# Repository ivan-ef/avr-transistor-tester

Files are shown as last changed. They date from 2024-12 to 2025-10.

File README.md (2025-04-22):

# AVR Transistor Tester

Component/Transistor tester based on famous [AVR Transistor Tester](https://www.mikrocontroller.net/articles/AVR_Transistortester) project. The reason I decided to create a custom PCB is that currently there is not good kit or complete device available that would fit my wishes:

- ATMega644 MCU
- 2.4" 65K colors LCD
- Rotary encoder
- USB-C charger with Li-Po battery
- Higher grade/precision components

Most of Chinese versions are starting to use fake or non-original Microchip MCUs that prevents their software upgrades and economy on components makes them less accurate. I didn't include a lot of hardware options, because I primarily using the device for measuring passive components and transistors used in guitar pedals building.

## Complete unit

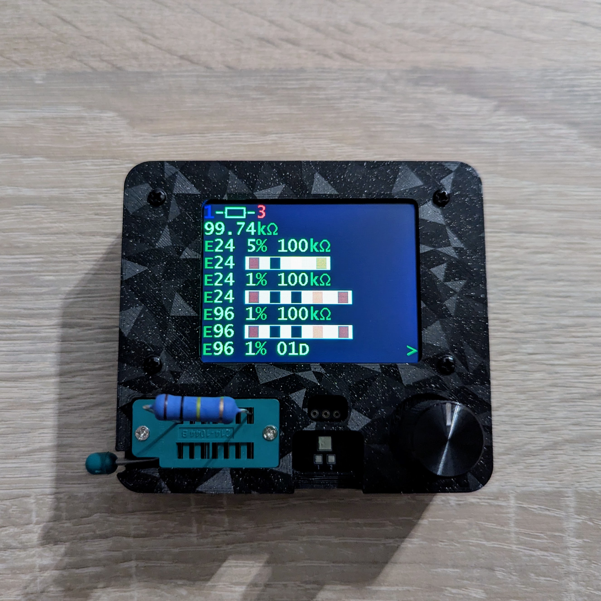
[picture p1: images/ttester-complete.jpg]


## PCB

I used SMD assembly service at JLCPCB and ended up with a set 5 PCBs cost around 25$ each. But since SMD components used there is not the smallest size ones, it is 100% possible to solder everything by hand.

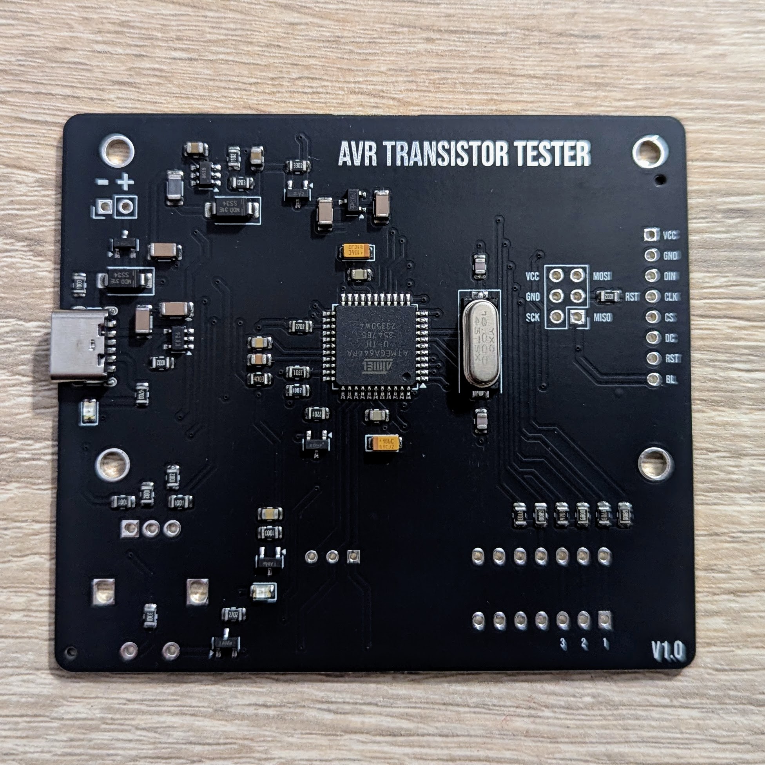
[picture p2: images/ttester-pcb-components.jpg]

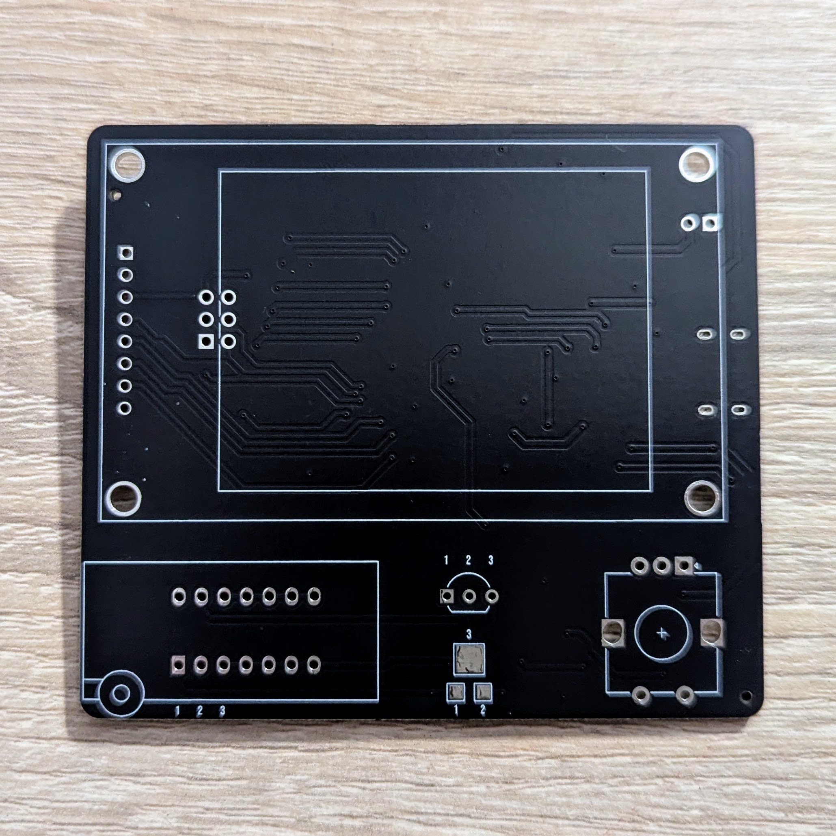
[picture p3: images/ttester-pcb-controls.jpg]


## Schematic

[PDF](https://github.com/vitaliy-bobrov/avr-transistor-tester/blob/main/schematic.pdf)

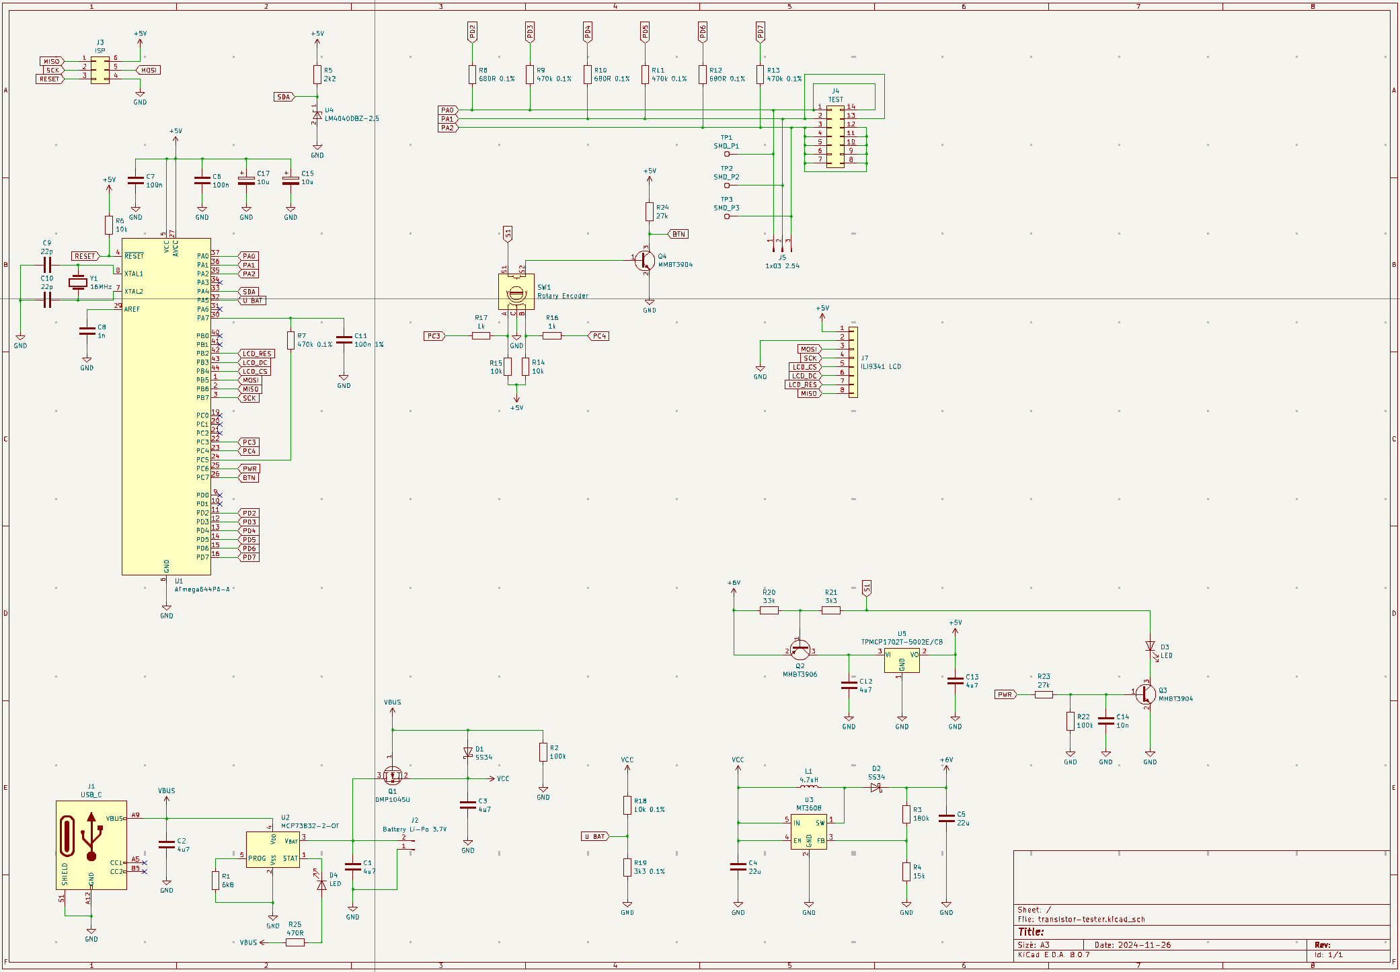
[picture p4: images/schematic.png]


## Hardware

PCB has almost everything as SMD assembly and requires a few components to be soldered by hand:

- Rotary Encoder - basically any common one would work here, but I've used BOURNS PEC11R-4220K-S0024. It is available at most big components suppliers. My personal choice was [TME](https://www.tme.eu/pl/details/pec11r-4220k-s0024/enkodery-inkrementalne/bourns/).
- ZIF 14 pin socket - again you could use any common one. I used CONNFLY DS1044-140G from [TME](https://www.tme.eu/pl/details/ds1044-140g/podstawki-testowe/connfly/)
- 2.4" 65K colors LCB. Not sure if other ILI9341 controller based would have the same pins/size. I used [Waveshare 18366](https://www.waveshare.com/2.4inch-lcd-module.htm) which is not expensive and commonly available. At [TME](https://www.tme.eu/pl/details/wsh-18366/wyswietlacze-lcd-graficzne/waveshare/18366/) too ;)
- 2.54mm spaced 2x3 pins for ISP - this could be left without pins soldered, then just ensure you have good contact between the PCB and programming pins.
- 2.54mm 3 pin socket for components/transistors - just alternative for ZIF socket
- Any Li-Po or Li-Ion battery with work with the charger IC, but the PCB was designed with Li-Po in mind due to size. I used [550mA battery](https://www.tme.eu/pl/details/aky-lp503040/akumulatory/akyga-battery/aky0185/), but you could use any other that would fit about 55x50mm size.

## Software

The software used in m-software version 1.55m (see [docs](https://github.com/madires/Transistortester-Warehouse/tree/master/Documentation)), but k-software could be used as well. The pins assignment is based on project docs suggested one. Precompiled version is in the [software](https://github.com/vitaliy-bobrov/avr-transistor-tester/blob/main/software/) folder.

### Software compilation

1. Install AVR tools for your operating system and programmer you are using (ex. avrdude)
2. Navigate to software folder
3. Run `make`
4. Connect programmer to the ISP pins on the PCB
5. Run `make fuses` to set MCU fuses
6. Run `make upload` to upload firmware

## Enclosure

I designed a simple 3D printable enclosure that fits the PCB and provides easy access to ISP pins and USB-C charger. STEP files are located in the [3d-enclosure](https://github.com/vitaliy-bobrov/avr-transistor-tester/blob/main/3d-enclosure/) folder. Printing profile is available at [MakerWorld](https://makerworld.com/en/models/883799#profileId-838469) which would be handy if you have a BambuLab 3D printer.

The assembled PCB with display is mounted to enclosure using spacers that came with Waveshare display using 4 x M2x8mm and 4 x M2x16mm screws. the battery is fixed on the backplate with double sided 3M foam.

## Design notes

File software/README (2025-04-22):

------------------------------------------------------------------------------

            ReadMe for the Component Tester firmware (m-firmware)

        (c) 2012-2025 by Markus Reschke (madires@theca-tabellaria.de)

------------------------------------------------------------------------------

Last edit:   2025-03-27
For version: 1.55m

Content
  - About
  - Safety Advice
  - License
    - Additional Disclaimer
  - What's different?
  - Source Code
  - Supported Hardware
  - Building the Firmware
  - Busses & Interfaces
    - I2C/SPI
    - TTL Serial
    - OneWire
  - Displays
    - Fonts and Symbols
    - HD44780
    - ILI9163
    - ILI9341/ILI9342
    - ILI9481
    - ILI9486
    - ILI9488
    - PCD8544
    - PCF8814
    - SH1106
    - SSD1306
    - ST7036
    - ST7565R
    - ST7735
    - ST7920
    - STE2007/HX1230
    - VT100 Terminal
  - Test push button and other input options
    - Test Key
    - Rotary Encoder
    - Increase/Decrease Buttons
    - Touch Screen
  - User Interface
    - Buzzer
  - Communication with PC
    - Serial Output
    - Automation
    - VT100 Output
  - Power-On
  - Probing
  - Battery Monitoring
  - Power Off
  - Menu
    - PWM Tool
    - Square Wave Generator
    - Zener Tool
    - Logic Probe
    - Continuity Check
    - ESR Tool
    - Capacitor Leakage Check
    - R/C/L Monitors
    - LC Meter
    - Frequency Counter
      - Basic Counter
      - Extended Counter
    - Ring Tester
    - Event Counter
      - Trigger Output
    - Rotary Encoder
    - Contrast
    - IR RC Detector/Decoder
    - IR RC Transmitter
    - Opto Coupler Tool
    - Photodiode Check
    - Diode/LED Quick-Check
    - Servo Check
    - OneWire Scan
    - DS18B20/DS18S20 Temperature Sensors
    - DHTxx Temperature & Humidity Sensors
    - MAX6675/MAX31855 Thermocouple Converters
    - BH1750 Ambient Light Sensor
    - INA226 Power Monitor
    - Flashlight
    - Voltmeter 0-5 V DC
    - Self Test
    - Self Adjustment
    - Save/Load
    - Show Values
    - Font/Symbols
    - Power Off
    - Exit
    - Order of Menu Items
  - Resistors
  - Capacitors
  - Inductors
  - Discharging Components
  - ADC Oversampling
  - Displaying Results
    - Additional Hints
      - BJTs
      - FETs
      - TRIACs
      - CLDs
      - SUS/SBSs
  - Unsupported Components
  - Workarounds for some Testers
  - Known Issues
  - Support
  - Change Log
  - Remote Commands
  - Helpful Links
  - References

* About

The Component Tester is based on the project of Markus Frejek [1&2] and the
successor of Karl-Heinz Kübbeler [3&4]. It's an alternative firmware for
Karl-Heinz' current Transistortester circuit and comes with several changes in
the user interface and the methods used for probing and measuring. It also
offers a few additional features. While Karl-Heinz provides an official
release supporting also older ATmega MCUs, this firmware does require an
ATmega with 32 kB flash at least.

Hints:
- Run the self-adjustment for a new tester or if you've done any
  modifications, like a firmware update or changing probe leads.
- The Component Tester isn't an LCR meter. It can measure capacitance and
  inductance within some limits.

* Safety Advice

The Component Tester is no DMM! It's a simple tester for components capable
of measuring several things. The probes aren't protected in any way and
won't survive higher voltages than 5 V. Don't use the tester for live circuits!
Just use it for unsoldered electronic components! If you test a capacitor make
sure it's discharged before connecting the probes. This isn't just the Safety
Sally, your life may be at risk if you connect the probes to a live circuit
or a power supply (or even mains). 

* License

The original author hasn't provided any information about the licence under
which the firmware is distributed. He only stated that it's open source and
any commercial user should contact him. Unfortunately we (Karl-Heinz and I)
haven't found any way to contact him. To remedy this problem I've chosen an
open source license at 2016-01-01, after giving the original author more than
sufficient time to tell us his wishes regarding the license. Since the source
code of this firmware version is a major rewrite with tons of new code and
features, I think that this approach is justified.

Licensed under the EUPL v. 1.2

+ Additional Disclaimer

Product or company names are possibly trademarks of the respective owners.

* What's different?

Karl-Heinz has done a really great documentation of the tester. I recommend
to read it. Therefore I'll tell you just about the major differences to the
k-firmware:

- user interface
  + No worries! ;)
  + touch screen
  + remote commands
  + two sets of adjustment values
- adaptive component discharge function
- resistance measurement
  + dedicated method for resistances <10 Ohms (instead of using ESR check)
- capacitance measurement
  + starts at 5 pF
  + additional method for caps from 4.7 µF up to 47 µF
  + correction/compensation method
- no SamplingADC() for very low capacitance or inductance
- diodes
  + detection logic
- BJTs
  + V_f is interpolated for a more suitable (virtual) I_b based on hFE
  + detection of Germanium BJTs with high leakage current
  + detection of Schottky-clamped BJTs
- JFETs
  + detection of JFETs with very low I_DSS
- TRIACs
  + detection of MT1 and MT2
- IR RC detector and decoder
- IR RC transmitter
- opto coupler check
- RC servo check
- OneWire (plus sensors DS18B20 and DS18S20)
- DHTxx Sensors
- event counter
- ring tester (LOPT/FBT tester)
- logic probe
- continuity check
- MAX6675/MAX31855 thermocouple converters
- BH1750 Ambient Light Sensor
- INA226 Power Monitor
- flashlight / general purpose switched output
- structured source code
- simple frameworks for displays and data busses
- some more I couldn't think of right now

There are more details in the sections below.

* Source Code

The first m-firmware was based on Karl-Heinz' source code. A lot of cleaning
up was done, like more remarks, renamed variables, re-structured functions,
large functions splitted up into several smaller ones and what have you. After
that the m-firmware moved on to become an independent version. For example,
simple frameworks for displays and interface busses were added. I hope the
code is easy to read and maintain.

You can download the lastest firmware from following sites:
- https://github.com/madires/Transistortester-Warehouse
- https://github.com/kubi48/TransistorTester-source/tree/master/Markus
  (https://github.com/Mikrocontroller-net/transistortester/tree/master/Software/Markus)

* Supported Hardware

The firmware runs on all testers which are compatible with the standard
circuit shown in Karl-Heinz' documentation and which use one of the
following MCUs:
  - ATmega 328
  - ATmega 324/644/1284
  - ATmega 640/1280/2560

You can customize pin assigments if required. The display may be a character
or graphic type (monochrome or color). Please see section 'Displays' for
supported controllers.

Following hardware options are supported:

  user interface
  - rotary encoder
  - additional push buttons (in/decrease)
  - touch screen
  - serial interface (TTL, RS232, USB-serial adpater) 
  - buzzer

  enhancements
  - external 2.5 V voltage reference
  - fixed adjustment cap
  - protection relay for discharging caps

  additional checks and measurements
  - Zener check / measurement of external voltage < 50 V
  - basic frequency counter
  - extended frequency counter
    with prescaler and crystal oscillators for low and high frequencies
  - fixed IR RC receiver
  - LC meter
  - ring tester (LOPT/FBT tester)
  - logic probe
  - fixed DS18B20/DS18S20 temperature sensors
  - MAX6675/MAX31855 thermocouple converters
  - BH1750 ambient light sensor
  - INA226 power monitor
  - flashlight / general purpose switched output

* Building the Firmware

First edit the Makefile to specify your MCU model, frequency, oscilator
type and programmer settings. All other settings are moved to a global
config.h and a MCU specific config-<MCU>.h. The file 'Clones' lists
settings for various tester versions/clones. If you have a tester not listed,
please email the settings to the author to help other users.

In config.h please choose hardware and software options, the language for the
UI, and change any default values if required. All settings and values are
explained in the file, so I won't discuss them here in depth. 

Hardware options:
- additional keys
  - rotary encoder
  - increase/decrease push buttons
  - touch screen
- 2.5 V voltage reference
- relay based cap discharger
- Zener voltage measurement
- frequency counter (basic and extendend version)
- event counter
- LC Meter
- ring tester (LOPT/FBT tester)
- IR detector/decoder for remote controls
  (fixed IR receiver module)
- fixed cap for self-adjustment of voltage offsets
- SPI bus (bit-bang and hardware)
- I2C bus (bit-bang and hardware)
- TTL Serial (bit-bang and hardware)
- OneWire bus (bit-bang)
- ...

The external 2.5 V voltage reference should be only enabled if it's at least
10 times more precise than the voltage regulator. Otherwise it would make
the results worse. If you're using an MCP1702 with a typical tolerance of
0.4 % as voltage regulator you really don't need a 2.5 V voltage reference.

And of course the software options:
- PWM generator (2 variants)
- inductance measurement
- ESR measurement and in-circuit ESR measurement
- check for rotary encoders
- squarewave signal generator (requires additional keys)
- IR detector/decoder for remote controls
  (IR receiver module connected to probes)
- IR RC transmitter (IR LED with driver transistor)
- check for opto couplers
- servo check (requires additional keys, display with >2 lines)
- detection of UJTs
- capacitor leakage check
- DS18B20/DS18S20 temperature sensors
- color coding for probes (requires color graphics display)
- output of components found also via TTL serial, e.g. to a PC
- remote commands for automation via TTL serial
- output of reverse hFE for BJTs
- DHT11/22 temperature and humidity sensor
- ...

Please choose the options carefully to match your needs and the MCU's
ressources, i.e. RAM, EEPROM and flash memory. If the firmware exceeds the
MCU's flash size, try to disable some options you don't need.

Available UI languages:
- Brazilian Portuguese
  - provided by wandows@EEVblog
- Czech
  - provided by Kapa
  - font based on ISO 8859-1
- Czech 2
  - provided by Bohu
  - font with Czech characters based on ISO 8859-2
- Danish
  - provided by glenndk@mikrocontroller.net
  - needs minor changes in the font
- English (default)
- French
  - provided by moimem@EEVblog
- German
- Italian
  - provided by Gino_09@EEVblog
- Polish
  - provided by Szpila
- Romanian
  - provided by Dumidan@EEVblog
- Russian
  - provided by indman@EEVblog
  - font with cyrillic characters based on Windows-1251
- Russian 2
  - provided by hapless@@EEVblog
  - font with cyrillic characters based on Windows-1251
  - alternative text 
- Spanish
  - provided by pepe10000@EEVblog

For number values a decimal fraction is indicated by a dot, but you can change
that to a comma if you like by enabling the corresponding setting.

For MCU specific settings, like pin assignments and display, edit 
config_<MCU>.h:
- ATmega 328                config_328.h
- ATmega 324/644/1284       config_644.h
- ATmega 640/1280/2560      config_1280.h

The display has to provide 2 lines with 16 characters each, at least. For
graphic displays select a font which is small enough to match the
requirements.

After editing the Makefile, config.h and config-<MCU>.h please run 'make' or
whatever toolchain you have to compile the firmware. This will create two
files:
- ComponentTester.hex   firmware in Intel hex format
- ComponentTester.eep   EEPROM data in Intel hex format

The firmware will be written to the Flash and the EEPROM data to the EEPROM.
The data contains two sets of default adjustment values, texts and tables.
When you update the firmware and like to keep the old adjustment values in the
EEPROM you can enable DATA_FLASH in config.h to move texts and tables into the
firmware. In that case only the firmwmare needs be programed, the EEPROM stays
untouched.

The Makefile provides following additional targets:
- clean     to delete all object and firmware files
- fuses     to set the ATmega's fuse bits (via avrdude)
- upload    to program the firmware and EEPROM data (via avrdude)
- prog_fw   to program only the firmware (via avrdude)
- prog_ee   to program only the EEPROM data (via avrdude)

Hints on compiler/linker optimizations:
- There are multiple lines of CFLAGS and LDFLAGS with compiler/linker options
  in the Makefile. You'll find a few lines commented out which contain
  additional optimization options to reduce the firmware size. Those are not
  supported by all compilers. So please feel free to experiment. ;)

Hints on special settings in the Makefile:
- In a linux/unix environment you can enable OPTIMIZE_VECTORS to optimize the
  interrupt vector table to reduce the firmware size.

* Busses & Interfaces

+ I2C/SPI

Some displays and other hardware might need I2C or SPI for connecting to the
MCU. Therefore the firmware includes drivers for both bus systems. To cope
with different pin assignments of the various testers the bus drivers support
bit-bang and hardware operation modes. The bit-bang mode can use any IO pins
on the same port, while the hardware mode uses the dedicated bus pins of the
MCU. The drawback of the bit-bang mode is its speed, it's slow. The hardware
mode is much faster. You can spot the difference in speeds easily with a high
resolution color LCD module.

For ATmega 328 based testers the bit-bang mode is needed in most cases due to
the circuit. The ATmega 324/644/1284 has more I/O pins and the different pin
assignment for the circuit allows to use the dedicated bus pins for the
hardware mode.

Since SPI or I2C are primarily used by the display module, they can be
configured in the display section of config-<MCU>.h. Alternatively you can
also enable I2C and SPI in config.h, and set ports and pins in dedicated
sections in config-<MCU>.h (look for I2C_PORT or SPI_PORT).

If you select bit-bang SPI and enable the read mode (SPI_RW) please make sure
to set also SPI_PIN and SPI_MISO. See the SPI section in config-<MCU>.h for
an example.

When connecting multiple ICs to the SPI bus, each IC needs to be controlled by
a dediacted /CS signal. Only in the case of one single IC on the SPI bus that
IC's /CS can be tied to ground.

Hint for bit-bang SPI:
- If, in the case of a high MCU clock rate, the SPI bus becomes too fast for
  the display please add the option 'SPI_SLOWDOWN' to the display setup in
  config-<MCU>.h, or enable it in config.h.

+ TTL Serial

The tester can also provide a TTL serial interface. In case it's used for
communication with a PC it should be combined with a USB to TTL serial
converter or a classic RS-232 driver. The firmware makes use of the MCU's
hardware UART or a bit-bang software UART. The TTL serial interface is enabled
in config.h (see section "Busses") and the port pins are defined in
config-<MCU>.h (look for SERIAL_PORT).

The software UART has the drawback that the TX line will not stay high all
the time when idle. This happens because of the way the MCU port pins are
driven. To remedy this the port pin driving would have to be changed causing
a larger firmware. But this issue doesn't seem to cause any trouble with most
USB to TTL serial converters. In case you see any problem try to add a pull-up
resistor (10-100 kOhms) to the TX pin to keep the signal at high level when
idle.

The default setting for the TTL serial is 9600 8N1:
  - 9600 bps
  - 8 data bits
  - no parity
  - 1 stop bit
  - no flow control

+ OneWire

Another supported bus is OneWire which can use either the probes/test pins (
ONEWIRE_PROBES) or a dedicated I/O pin (ONEWIRE_IO_PIN). The driver is designed
for standard bus speed and externally powered clients (not parasitic-
powered).

Pin assignment for probes:
  Probe #1:  Gnd
  Probe #2:  DQ (data)
  Probe #3:  Vcc (current limited by 680 ohms resistor)
  An external pull-up resistor of 4.7 kOhms between DQ and Vcc is required!

Related tools which require a single client to be connected to the bus can
optionally output the client's ROM code (ONEWIRE_READ_ROM). In case of a CRC
error or if multiple clients are connected the output will be '-'. When the
ROM code is zero there's a read issue. Otherwise the first part of the ROM
code shows the device family and the second part the serial number.

* Displays

At the moment following display controllers are supported:
- HD44780 (character display, 2-4 lines with 16-20 characters)
- ILI9163 (color graphic display 128x160)
- ILI9341/ILI9342 (color graphic display 240x320 or 320x240)
- ILI9481 (color graphic display 320x480, partly untested)
- ILI9486 (color graphic display 320x480, partly untested)
- ILI9488 (color graphic display 320x480, partly untested)
- PCD8544 (graphic display 84x48)
- PCF8814 (graphic display 96x65)
- SH1106 (graphic display 128x64)
- SSD1306 (graphic display 128x64)
- ST7036 (character display, 3 lines with 16 characters, untested)
- ST7565R (graphic display 128x64)
- ST7735 (color graphic display 128x160)
- ST7920 (graphic display up to 256x64)
- STE2007/HX1230 (graphic display 96x68)
- VT100 Terminal (via serial interface)

Take care about the LCD's supply voltage and logic levels! Use a level shifter
if required. A simple level shifter with in-series resistors relying on the
display controller's internal clamping diodes may work, but only for low speed
busses like bit-bang SPI. Therefore I recommend to use proper level shifter
ICs.

To save a few IO pins you can hardwire the /CS and /RES lines via pull-up/down
resistors for nearly all displays and comment out the corresponding IO pins in
the configuration (config_<MCU>.h) as long as the display is the only device
on the interface bus.

If the display doesn't show anything after double checking the wiring, please
try different contrast settings (config_<MCU>.h). 

Most graphic displays provide settings to change the image orientation, e.g.
for rotating the image by 90° and mirroring the image horizontally or
vertically. That way the image can be adjusted for each tester as needed.
For color graphic displays additional settings are available. In the normal
color mode the tester uses several colors which can be changed by editing
the colors.h file. By commenting out LCD_COLOR the two-color mode is enabled
and the pen color will be COLOR_PEN, while the background color is set to
COLOR_BACKGROUND. In case the RGB base colors red and blue are reversed
enable LCD_BGR to swap the red and blue color channels. Some displays have
reversed RGB sub-pixels and the display controller doesn't know about that.

Hint for ATmega 328:
If you connect a rotary encoder to PD2/PD3, please connect the display's /CS to
PD5 and set LCD_CS in config_328.h (applies to graphic displays). Otherwise
the rotary encoder would screw up the display by interfering with the data bus.

+ Fonts and Symbols

The display configuration includes also a font and optionally a set of
component symbols. Suitable fonts and symbols are listed for each display in
config_<MCU>.h. For a graphic display you can choose from multiple fonts in
most cases. The symbols are activated by the SW_SYMBOLS switch in config.h.

If you prefer the old style of component symbols you can still use them by
changing the symbols setting to SYMBOLS_<size>_OLD_<format>.h.

For test purposes you can enable a menu function to show all font characters (
SW_FONT_TEST) or all component symbols (SW_SYMBOL_TEST).

Hint:
- When on a color display characters seem to be shifted slightly up or down
  based on the color, this is caused by the construction of the display, i.e.
  by the positioning of the RGB subpixels.

+ HD44780

The HD44780 is driven in 4 bit mode. The pin assignment for the parallel
port is:

  display     config-<MCU>.h   default      remark
                               ATmega 328
  ---------------------------------------------------------------
  DB4         LCD_DB4          PD0
  DB5         LCD_DB5          PD1
  DB6         LCD_DB6          PD2
  DB7         LCD_DB7          PD3
  RS          LCD_RS           PD4
  R/W                          Gnd
  E           LCD_EN1          PD5

You can also drive the LCD via a PCF8574 based I2C backpack which requires
I2C to be enabled. The I2C address has to be specified too. The pin
assignment defines how the LCD is connected to the PCF8574:

  display     config-<MCU>.h   default      remark
  ---------------------------------------------------------------
  DB4         LCD_DB4          PCF8574_P4
  DB5         LCD_DB5          PCF8574_P5
  DB6         LCD_DB6          PCF8574_P6
  DB7         LCD_DB7          PCF8574_P7
  RS          LCD_RS           PCF8574_P0
  R/W         LCD_RW           PCF8574_P1
  E           LCD_EN1          PCF8574_P2
  LED         LCD_LED          PCF8574_P3

For a low active backlight please enable LCD_BACKLIGHT_LOW.

+ ILI9163

The ILI9163 is driven by 4-wire SPI. The pin assignment is:

  display     config-<MCU>.h   default      remark
                               ATmega 328
  ---------------------------------------------------------------
  /RESX       LCD_RES          PD4          optional
  /CSX        LCD_CS           PD5          optional
  D/CX        LCD_DC           PD3
  SCL         LCD_SCL          PD2          SPI clock
  SDIO        LCD_SDA          PD1          SPI MOSI

You might need to play with the x/y flip settings to get the correct
orientation for your display. If necessary you can also offset the x
direction. With LCD_LATE_ON enabled the tester starts with a cleared display
causing a slight delay at power-on. Otherwise you'll see some random pixels
for a moment.

+ ILI9341/ILI9342

The ILI9341/ILI9342 is driven by 4-line SPI or an 8-bit parallel bus. The pin
assignment for 4-line SPI is:

  display     config-<MCU>.h   default      remark
                               ATmega 328
  ---------------------------------------------------------------
  /RES        LCD_RES          PD4          optional
  /CS         LCD_CS           PD5          optional
  D/C         LCD_DC           PD3
  SCK         LCD_SCK          PD2          SPI clock
  SDI         LCD_SDI          PD1          SPI MOSI
  SDO         LCD_SDO          -            ILI9341 only, not used yet

For 8-bit parallel:

  display     config-<MCU>.h   default      remark
                               ATmega 2560
  ---------------------------------------------------------------
              LCD_PORT         PORTB
  /RESX       LCD_RES          PB4          optional
  /CSX        LCD_CS           PB5          optional
  D/CX        LCD_DC           PB7
  WRX         LCD_WR           PB0
  RDX         LCD_RD           PB6          optional
              LCD_PORT2        PORTL
  D0          LCD_DB0          PL0          LCD_PORT2 pin #0
  D1          LCD_DB1          PL1          LCD_PORT2 pin #1
  D2          LCD_DB2          PL2          LCD_PORT2 pin #2
  D3          LCD_DB3          PL3          LCD_PORT2 pin #3
  D4          LCD_DB4          PL4          LCD_PORT2 pin #4
  D5          LCD_DB5          PL5          LCD_PORT2 pin #5
  D6          LCD_DB6          PL6          LCD_PORT2 pin #6
  D7          LCD_DB7          PL7          LCD_PORT2 pin #7

You might need to play with the x/y flip and rotate settings to get the
correct orientation for your display. And don't forget to set x and y dots
based on the controller (ILI9341 is 240x320 and ILI9342 is 320x240). Some
display modules disabled the ILI9341's extended command set (EXTC pin
connected to Gnd). In that case you might see a blurry or ghostly output
which can be fixed by enabling LCD_EXT_CMD_OFF.

Based on the relative high number of pixels the display output is somewhat
slow via SPI. A complete screen clear takes about 3 seconds for bit-bang SPI
and an 8 MHz MCU clock. Better use harwdare SPI or the parallel bus.

+ ILI9481 (partly untested)

The ILI9481 is driven by an 8-bit parallel bus, 16-bit parallel bus or
4-line SPI.

The pin assignment for 8-bit parallel is:

  display     config-<MCU>.h   default      remark
                               ATmega 2560
  ---------------------------------------------------------------
              LCD_PORT         PORTB
  /RESX       LCD_RES          PB4          optional
  /CSX        LCD_CS           PB5          optional
  D/CX        LCD_DC           PB7
  WRX         LCD_WR           PB0
  RDX         LCD_RD           PB6          optional
              LCD_PORT2        PORTL
  DB0         LCD_DB0          PL0          LCD_PORT2 pin #0
  DB1         LCD_DB1          PL1          LCD_PORT2 pin #1
  DB2         LCD_DB2          PL2          LCD_PORT2 pin #2
  DB3         LCD_DB3          PL3          LCD_PORT2 pin #3
  DB4         LCD_DB4          PL4          LCD_PORT2 pin #4
  DB5         LCD_DB5          PL5          LCD_PORT2 pin #5
  DB6         LCD_DB6          PL6          LCD_PORT2 pin #6
  DB7         LCD_DB7          PL7          LCD_PORT2 pin #7

The pin assignment for 16-bit parallel is the same as for 8-bit parallel
and additionally:

              LCD_PORT3        PORTC
  DB8         LCD_DB8          PC0          LCD_PORT3 pin #0
  DB9         LCD_DB9          PC1          LCD_PORT3 pin #1
  DB10        LCD_DB10         PC2          LCD_PORT3 pin #2
  DB11        LCD_DB11         PC3          LCD_PORT3 pin #3
  DB12        LCD_DB12         PC4          LCD_PORT3 pin #4
  DB13        LCD_DB13         PC5          LCD_PORT3 pin #5
  DB14        LCD_DB14         PC6          LCD_PORT3 pin #6
  DB15        LCD_DB15         PC7          LCD_PORT3 pin #7

Pin assignment for 4-line SPI:

  display     config-<MCU>.h   default      remark
                               ATmega 644
  ---------------------------------------------------------------
  /RES        LCD_RES          PB2          optional
  /CS         LCD_CS           PB4          optional
  D/C         LCD_DC           PB3
  SCL         LCD_SCL          PB7          SPI clock
  DIN/SDA     LCD_SDA          PB5          SPI MOSI

Because of the high resolution of the display and the RGB666 color schema (3
bytes per pixel) SPI is quite slow, even for hardware SPI and a 16 MHz MCU
clock. So I wouldn't recommend to use the SPI interface.

Usually you need to rotate the display (LCD_ROTATE) for correct output.
If neccessary you can also flip X and/or Y.

+ ILI9486 (partly untested)

The ILI9486 is driven by an 8-bit parallel bus, 16-bit parallel bus or
4-line SPI. And it uses the same pin assignment as the ILI9481.

+ ILI9488 (partly untested)

The ILI9488 is driven by an 8-bit parallel bus, 16-bit parallel bus or
4-line SPI. And it uses the same pin assignment as the ILI9481.

+ PCD8544

The PCD8544 is driven by SPI. The pin assignment is:

  display     config-<MCU>.h   default      remark
                               ATmega 328
  ---------------------------------------------------------------
  /RES        LCD_RES          PD4          optional
  /SCE        LCD_SCE          PD5          optional
  D/C         LCD_DC           PD3
  SCL         LCD_SCLK         PD2          SPI clock
  SDIN        LCD_SDIN         PD1          SPI MOSI

Since the display has just 84 pixels in x direction you'll get 14 chars per
line with a 6x8 font. So up to two chars might be not displayed. To mitigate
that you could shorten some texts in variables.h.

+ PCF8814

The PCF8814 is driven usually in the 3-wire SPI mode. The pin assignment for 
the 3-wire SPI (bit-bang only) is:

  display     config-<MCU>.h   default      remark
                               ATmega 328
  ---------------------------------------------------------------
  /RES        LCD_RESET        PD4
  /CS         LCD_CS           PD5          optional
  SCLK        LCD_SCLK         PD2          SPI clock
  SDIN        LCD_SDIN         PD1          SPI MOSI

If necessary you can rotate the output via the y-flip setting and pulling
the PCF8814's MX pin (x-flip) down or up.

+ SH1106 (partly untested)

The SH1106 is driven by 3-wire SPI, 4-wire SPI or I2C. 3-wire SPI requires
bit-bang mode and SPI_9 to be enabled. The pin assignment for 4-wire SPI is:

  display     config-<MCU>.h   default      remark
                               ATmega 328
  ---------------------------------------------------------------
  /RES        LCD_RESET        PD4          optional
  /CS         LCD_CS           PD5          optional
  A0          LCD_A0           PD3
  SCL (D0)    LCD_SCL          PD2          SPI clock
  SI (D1)     LCD_SI           PD1          SPI MOSI

For 3-wire SPI (bit-bang only):

  /RES        LCD_RESET        PD4          optional
  /CS         LCD_CS           PD5          optional
  A0                           Gnd
  SCL (D0)    LCD_SCL          PD2          SPI clock
  SI (D1)     LCD_SI           PD1          SPI MOSI

And for I2C:

  /RES        LCD_RESET        PD4          optional
  /CS                          Gnd
  SCL (D0)    I2C_SCL          PD1
  SDA (D1)    I2C_SDA          PD0
  SA0 (A0)                     Gnd (0x3c) / 3.3 V (0x3d)

Using the x/y flip settings you can change the output orientation if
neccessary. Many SH1106 based display modules need the x offset set to 2.
In case the pixel lines are all mixed up you can try to enable the sequential
COM pin layout (LCD_COM_SEQ).

+ SSD1306

The SSD1306 is driven by 3-wire SPI, 4-wire SPI or I2C. 3-wire SPI requires
bit-bang mode and SPI_9 to be enabled. The pin assignment for 4-wire SPI is:

  display     config-<MCU>.h   default      remark
                               ATmega 328
  ---------------------------------------------------------------
  /RES        LCD_RESET        PD4          optional
  /CS         LCD_CS           PD5          optional
  DC          LCD_DC           PD3
  SCLK (D0)   LCD_SCLK         PD2          SPI clock
  SDIN (D1)   LCD_SDIN         PD1          SPI MOSI

For 3-wire SPI (bit-bang only):

  /RES        LCD_RESET        PD4          optional
  /CS         LCD_CS           PD5          optional
  SCLK (D0)   LCD_SCLK         PD2          SPI clock
  SDIN (D1)   LCD_SDIN         PD1          SPI MOSI

And for I2C:

  /RES        LCD_RESET        PD4          optional
  SCL (D0)    I2C_SCL          PD1
  SDA (D1&2)  I2C_SDA          PD0
  SA0 (D/C)                    Gnd (0x3c) / 3.3 V (0x3d)

Using the x/y flip settings you can change the output orientation if
neccessary. In case the pixel lines are all mixed up you can try to enable
the sequential COM pin layout (LCD_COM_SEQ) and/or the reversed COM mapping (
LCD_COM_REMAP).

+ ST7036 (untested)

The ST7036 is driven by a 4-bit parallel interface or 4-wire SPI. The pin
assignment for the 4 bit parallel interface is:

  display     config-<MCU>.h   default      remark
                               ATmega 328
  ---------------------------------------------------------------
  DB4         LCD_DB4          PD0
  DB5         LCD_DB5          PD1
  DB6         LCD_DB6          PD2
  DB7         LCD_DB7          PD3
  RS          LCD_RS           PD4
  R/W                          Gnd          optional LCD_RW
  E           LCD_EN           PD5
  XRESET                       Vcc          optional LCD_RESET

And for 4-wire SPI:

  XRESET      LCD_RESET        PD4          optional
  CSB         LCD_CS           PD5          optional
  RS          LCD_RS           PD3
  SCL (DB6)   LCD_SCL          PD2          SPI clock
  SI (DB7)    LCD_SI           PD1          SPI MOSI

The ST7036i speaks I2C but isn't supported (yet). A special feature of the
ST7036 is a dedicated pin to enable an extended instruction set (pin EXT) which
is enabled usually. In case it's disabled the settings LCD_EXTENDED_CMD and
LCD_CONTRAST need to be commented out.

+ ST7565R

The ST7565R is driven by 4-line SPI. The pin assignment is:

  display     config-<MCU>.h   default      remark
                               ATmega 328
  ---------------------------------------------------------------
  /RES        LCD_RESET        PD0          optional
  /CS1        LCD_CS           PD5          optional
  A0          LCD_A0           PD1
  SCL (DB6)   LCD_SCL          PD2          SPI clock
  SI (DB7)    LCD_SI           PD3          SPI MOSI

You might need to play with the x/y flip and x-offset settings to get
the correct orientation for your display. The almost compatible NT7538
requires a long reset pulse (LCD_LONG_RESET).

+ ST7735

The ST7735 is driven by 4-wire SPI. The pin assignment is:

  display     config-<MCU>.h   default      remark
                               ATmega 328
  ---------------------------------------------------------------
  /RESX       LCD_RES          PD4          optional
  /CSX        LCD_CS           PD5          optional
  D/CX        LCD_DC           PD3
  SCL         LCD_SCL          PD2          SPI clock
  SDA         LCD_SDA          PD1          SPI MOSI

You might need to play with the x/y flip settings to get the correct
orientation for your display. With LCD_LATE_ON enabled the tester starts
with a cleared display causing a slight delay at power-on. Otherwise you'll
see some random pixels for a moment.

Meanwhile a semi-compatible LCD module appeared which won't run with the
standard driver. The solution is to use a modified driver (LCD_SEMI_ST7735
instead of LCD_ST7735) with the same settings. Note that the semi-compatible
LCD module doesn't support high SPI clock rates.

+ ST7920

The ST7920 can be driven in 4 bit parallel bus mode or SPI. The pin assignment
for the 4 bit parallel interface is:

  display     config-<MCU>.h   default      remark
                               ATmega 328
  ---------------------------------------------------------------
  /XRESET     LCD_RESET        Vcc          optional
  E           LCD_EN           PD5
  RS          LCD_RS           PD4
  RW          LCD_RW           Gnd          optional
  D4          LCD_DB4          PD0
  D5          LCD_DB5          PD1
  D6          LCD_DB6          PD2
  D7          LCD_DB7          PD3

And for SPI:

 /XRESET      LCD_RESET        PD4          optional
 CS (RS)      LCD_CS           PD5          optional
 SCLK (E)     LCD_SCLK         PD2          SPI clock
 SID (RW)     LCD_SID          PD1          SPI MOSI

Because of the ST7920's poor design only fonts with a width of 8 pixels can be
used. To cope with the horizontal 16 bit addressing grid I had to add a screen
buffer for characters.

+ STE2007/HX1230

The STE2007 is driven in the 3-wire SPI mode usually. The pin assignment for 
the 3-wire SPI (bit-bang only) is:

  display     config-<MCU>.h   default      remark
                               ATmega 328
  ---------------------------------------------------------------
  /RES        LCD_RESET        PD4          optional
  /CS         LCD_CS           PD5          optional
  SCLK        LCD_SCLK         PD2          SPI clock
  SDIN        LCD_SDIN         PD1          SPI MOSI

If necessary you can rotate the output via the x/y flip settings.

+ VT100 Terminal

The VT100 driver replaces a LCD display and outputs everything to a VT100 serial
terminal. The configuration section for VT100 includes already the activation of
the TTL serial interface. Be aware that the VT100 driver will disable other
options related to the serial interface which might interfere with the output.

* Test push button and other input options

The tester's primary control is the test key, but additional input options
are supported also for a more convenient operation, while some functions
require those.

+ Test Key

The test key starts the tester and also controls the user interface. For that
purpose the tester differentiates between a short and a long key press (0.3 s).
The short key press is typically used to proceed with something or to select
a menu item. The long key press performs a context specific action. There's
also a double-press, i.e. the test key is pressed twice quickly (also context
specific).

If the tester expects you to press a key it will tell you that by displaying
a cursor at bottom right of the LCD. A steady cursor signals that more
information will be displayed and a blinking cursor informs you that the tester
will resume the probing loop. The cursor is supressed for menus and some tools,
because it's obvious that a key press is neccessary.  

Optionally you can enable key hints if your tester has additional keys and a
display with a sufficient number of text lines (see UI_KEY_HINTS in config.h).
A hint about the key usage is displayed instead of the cursor, if available.
At the moment there's only one such hint for the probing (Menu/Test).

+ Rotary Encoder (hardware option)

With a rotary encoder you'll get some extra functionality with the user
interface, but that's context specific. The additional functionality is
described in the sections below, if applicable. Some functions make use of
the encoder's turning velocity to allow larger changes or steps of values.

The algorithm for reading the encoder considers the number of Gray code
pulses per step or detent (ENCODER_PULSES). Most rotary encoders have 2 or 4
Gray code pulses per detent. Also the number of steps or detents per complete
360 degrees turn is taken into account (ENCODER_STEPS). You can use that
value to finetune the detection of the turning velocity to optimize the
feedback. A higher value slows the velocity down, while a lower value speeds
it up. In case the encoder's turning direction is reversed, simply swap the
MCU pin definitions for A and B in config_<MCU>.h.

The detection of the turning velocity measures the time for two steps. So you
need to turn the encoder at least by two steps for a mid-range velocity. For
very high velocities it's three steps. A single step results in the lowest
velocity.

+ Increase/Decrease Buttons (hardware option)

If you prefer push buttons over a rotary encoder you can add a pair of push
buttons as alternative. The push buttons are wired the same way as the rotary
encoder (pull-up resistors, low active). For a speed-up functionality similar
to the encoder's turning velocity keep pressing the push button. A long button
press will increase the "speed" as long as you keep pressing the button.

+ Touch Screen (hardware option)

Another input option is a touch screen. Please note that the screen should be
large enough and support approximately 8 text lines with 16 characters each.
To save precious space on the display the user interface doesn't show icons
to touch. It simply has invisible touch bars at the left and right (each 3
characters wide), also at the top and the bottom (2 lines high) and one at the
center area. The left and top bars are for decreasing a value or moving up in
a menu, while the bottom and right bars are for increasing a value or moving
down in a menu. Actually they do the same as a rotary encoder. Touching a bar
longer results in a speed-up if supported by a function or tool (similar to
turning the rotary encoder faster). The center bar acts as a software version
of the test key, but it won't power the Zener diode test option for example.

The touch screen needs an adjustment for proper operation. The adjustment is
automatically started after powering the tester on, when no adjustment values
are stored in the EEPROM. You can also run the adjustment via the main menu.
The procedure is straight forward. If you see an asterisk (yellow * on color
displays), simply touch it. After that the tester clears the asterisk and
displays the native x/y position. The first adjustment point is at the top
right, and the second point at the bottom left. Based on the result the tester
may try the adjustment up to three times. You can skip the procedure any time
by pressing the test key.

If you have problems with the adjustment like bad x/y positions or an error
after the first adjusment round, please check the orientation of the touch
screen in relation to the display. The driver has options to flip or rotate
the orientation. The display's top left is assumed to be the zero position.
Some hints about the required settings for specific values of x and y:

  first adjustment point: top right

  x     y     settings
  ----------------------------------------
  low   low   TOUCH_FLIP_X
  low   high  TOUCH_FLIP_X & TOUCH_FLIP_Y
  high  low   none
  high  high  TOUCH_FLIP_Y

Don't forget to save the offsets after a successful adjustemnt (main menu:
save).

Supported touch screen controllers:
- ADS7843 / XPT2046

You'll find the configuration options below the display section in
config-<MCU>.h (currently just config_644.h and config_1280.h because the
ATmega 328 doesn't provide enough IO pins).

* User Interface

There are several options to make the output for displays more fancy and easier
to read.

For displays with more then two text lines:
- show key hints instead of cursor if available (UI_KEY_HINTS)
- center-align infos and some other texts (UI_CENTER_ALIGN)
- display battery status in the last line after showing the probing result (
  UI_BATTERY_LASTLINE)
- display measurement values of self-test/adjustment page-wise (
  UI_TEST_PAGEMODE, requires >= 6 text lines)

For graphic displays:
- all options listed before
- fancy pinout with symbols for three-legged semiconductors (SW_SYMBOLS, not
  for low resolution displays)
- show right-hand probe numbers of fancy pinout above and below symbol (
  UI_PINOUT_ALT)
- disable text based pinout for three-legged semiconductors (UI_NO_TEXTPINOUT,
  when SW_SYMBOLS is enabled)
- disable text based pinout of body diode for MOSFETs (
  UI_NO_BODYDIODE_TEXTPINOUT)
- display probe/testpin IDs with reversed colors (UI_PROBE_REVERSED)
- display question mark symbol in case of a failed test run (UI_QUESTION_MARK)
- display Zener diode symbol in any Zener check (UI_ZENER_DIODE) 
- display quartz crystal symbol for LF/HF modes in extended frequency
  counter (UI_QUARTZ_CRYSTAL)
- display OneWire device symbol in DS18B20, DS18S20 and DHTXX tool
- scroll menues page-wise instead of item-wise to speed up menu operation
  (UI_MENU_PAGEMODE)
- display small battery symbol to indicate battery status (UI_BATTERY)

For color graphic displays:
- all options listed before
- color coding for probes/testpins (UI_PROBE_COLORS)
- dedicated color for titles (UI_COLORED_TITLES)
- dedicated color for values (not units, UI_COLORED_VALUES)
- dedicated color for cursor and key hints (UI_COLORED_CURSOR)
- color code for resistors (SW_R_E24_5_CC, SW_R_E24_1_CC and SW_R_E96_CC)

+ Buzzer (hardware option)

If you like to have an audible indicator you can add an active buzzer (with
integrated oscillator) or a passive buzzer. The buzzer is controlled via a
fixed pin (see BUZZER_CTRL in config_<MCU>.h) and can be driven directly (
< 20 mA) or by a transistor (NPN or n-channel MOSFET).

The passive buzzer generates short beeps with 2.5 and 5 kHz.

At the moment the buzzer is used for
- continuity check (SW_CONTINUITY_CHECK)
- confirmation beep when probing is done (UI_PROBING_DONE_BEEP)
- confirmation beep for valid frame/packet in IR receiver/decoder
  (SW_IR_RX_BEEP)
- logic probe (HW_LOGIC_PROBE)
- voltmeter 0-5 V DC when a threshold is exceeded (SW_METER_5VDC)
- INA226 power monitor when power threshold is exceeded (INA226_POWER_ALARM)

* Communication with PC

The tester can support a TTL serial interface for communication with a PC.
This could be a TX-only connection for outputting components found or a
bidrectional one for automation. In both cases the TTL serial interface needs
to be enabled in config.h (see section "Busses").

Special characters are replaced with standard ones, for example the omega (
Ohms) becomes a simple R.

conversion table:
  diode symbols       |>  <|
  capacitor symbol    ||
  omega               R
  micro / µ           u
  resistor symbol     []

Hints:
- 9600 8N1
- newline is <CR><LF>

+ Serial Output

The tester outputs components found to a PC running a simple terminal program
when this feature is enabled (see UI_SERIAL_COPY in section "misc settings"
in config.h). The serial output follows the output on the LCD display but only
for the components found. There is no serial output for menus and tools besides
the results of the opto coupler check.

+ Automation

The automation feature allows you to control the tester by remote commands
via a bidirectional serial connection. For enabling this feature please see
UI_SERIAL_COMMANDS in section "misc settings" in config.h. The default
behaviour of the tester will change slightly. The automation enforces the
auto-hold mode and the tester won't automatically check for a component after
powering on.

The command interface is fairly simply. You send a command and the tester will
respond. The communication is based on ASCII textlines and the commands are
case sensitive. Each command line has to be ended by a <CR><LF> or <LF> newline.
Be aware that the tester will only accept commands when waiting for user
feedback after powering on, displaying a component or running a menu function.
Response lines end with a <CR><LF> newline. See section "Remote Commands" for
a list of commands and their explanation.

+ VT100 Output

The tester can output everything to a VT100 terminal instead of a LCD display (
see VT100 in section "Displays"). To keep the layout of the output undisturbed
all other options for the serial interface are disabled.

* Power-On

A long key press while starting the tester selects the auto-hold mode. In that
mode the tester waits for a short key press after displaying a result before
it will continue. Otherwise the tester chooses the continuous (looping) mode by
default. You can reverse the operation mode selection in config.h (UI_AUTOHOLD).
After powering on, the firmware version is shown briefly.

A very long key press (2 s) will reset the tester to firmware defaults. This
might be handy if you have misadjusted the LCD contrast for example and can't
read the display anymore.

If the tester detects a problem with the stored adjustments values, it will
display a checksum error. That error indicates a corrupted EEPROM, and the
tester will use firmware defaults instead.

For a tester with a manual power switch instead of the soft-latching one used
by the reference design please enable POWER_SWITCH_MANUAL in config.h. In that
case the tester won't be able to power itself off.

There's an option available to enter the main menu after power-on when pressing
the test button twice at power-on (UI_MAINMENU_POWERON_BUTTON). The duration of
the first button press still controls the operation mode.

* Probing

After the startup the tester looks for a connected component to check. In
continuous mode it will automatically repeat the probing after a short pause.
If no component is found for several times the tester will power itself off.
In auto-hold mode (signaled by the cursor) the tester runs one probing cycle
and waits for a key press or a right turn of the rotary encoder before it will
proceed with the next cycle.

The cycle delay and automatic power-off for the continuous mode can be adjusted
by changing CYCLE_DELAY and CYCLE_MAX in config.h. There's an optional
automatic power-off for the auto-hold mode (POWER_OFF_TIMEOUT) which is only
active during probing cycles and in the main menu.

In both modes you can enter a menu with additional functions or power off
the tester. For details please see below.

With the buzzer hardware option you can enable a short confirmation beep for
a completed probing cycle (UI_PROBING_DONE_BEEP). There's also an option to
switch temporarily to the auto-hold mode after a component is found (when in
continuous mode, UI_AUTOHOLD_FOUND). This helps with reading the display
output.

* Battery Monitoring

Each probing cycling starts with the display of the battery voltage and a brief
status (ok, weak, low). The tester will power off when the low voltage
threshold is reached. The battery is checked regularly during operation.

The default configuration for the battery monitoring is set for a 9 V battery,
but it can be changed for most other power sources. Please see section
"power management" in config.h for all the settings.

The monitoring can be disabled by BAT_NONE, set to direct voltage check for
power sources lower than 5 V by BAT_DIRECT, or set for voltage check via a
voltage divider, specified by BAT_R1 and BAT_R2, by BAT_DIVIDER. Some testers
support an optional external power supply but don't allow its monitoring. In
this case enable BAT_EXT_UNMONITORED to prevent problems with the automatic
power-off by a low battery. This will also set the "ext" battery status when
powered by the external power source.

The thresholds for a weak and a low battery are set by BAT_WEAK and BAT_LOW
while BAT_OFFSET specifies any voltage drop caused by the circuit, e.g. a
reverse polarity protection diode and a PNP power control transistor.

You can enable the display of a small battery symbol to indicate the battery
status instead of the text based version (UI_BATTERY). There's also an option
to display the battery status in the last line after showing the probing result
(UI_BATTERY_LASTLINE).

* Power Off

While displaying the result of the last test a long key press powers the
tester off. The tester will show a good bye message and then power off. As
long as you press the key the tester stays powered on. This is caused by the
implementaion of the power control circuit.

* Menu

You'll enter the menu by two short key presses after the display of the last
component found or function performed. Simply press the test key twice quickly
(might need some practice :). If the rotary encoder option is enabled, a left
turn will also enter the menu. The old method by short circuiting all three
probes can be enabled too (UI_SHORT_CIRCUIT_MENU).

While in the menu, a short key press shows the next item in the menu and a
long key press runs the shown item. On a 2-line display you'll see a
navigation help at the bottom right. A '>' if another item follows, or
a '<' for the very last item (will roll over to the first item). On a
display with more than 2 lines the selected item is marked with an '*' at
the left side. 

With a rotary encoder you can move the items up or down based on the turning
direction and a short key press will run the displayed item, instead of moving
to the next item. Roll over is also enabled for the first item.

Normally the tester will return to the probing cycle after running a function
or tool. If you prefer to stay in the menu until an explicit "exit" you can
disable UI_MAINMENU_AUTOEXIT.

Some tools show you the pinout of the probe pins used before doing anything.
That info will be displayed for a few seconds, but can be skipped by a short
press of the test button.

For tools which generate a signal probe #2 is used as output by default. In
that case probe #1 and #3 are set to ground. If your tester is configured for a
dedicated signal output (OC1B) the probes aren't used and no probe pinout will
be displayed.

+ PWM Tool

This does what you would expect. :) Before compiling the firmware please
choose either the PWM generator with the simple user interface or the one with
the fancy interface for testers with rotary encoder and large displays. For
optional output of the pulse duration enable also PWM_SHOW_DURATION.

Pinout for signal output via probes:
  Probe #2:         output (with 680 Ohms resistor to limit current)
  Probe #1 and #3:  Ground

- Simple PWM

First you have to select the desired PWM frequency in a simple menu. Short key
press for the next frequency and a long key press starts the PWM output for
the shown frequency.

The duty ratio of the PWM starts at 50 %. A short key press of the test button
increases the ratio by 5 %, a long key press decreases the ratio by 5 %. To
exit the PWM tool press the test key twice quickly.

If you have a rotary encoder you can use it to select the frequency in the menu
and to change the PWM ratio in 1 % steps.

- Fancy PWM

Switch between frequency and ratio by pressing the test button. The selected
value is marked by an asterisk. Turn the rotary encoder clockwise to increase
the value or anti-clockwise to decrease it. As faster you turn the rotary
encoder as larger the step size becomes. A long key press sets the default
value (frequency: 1 kHz, ratio: 50 %). Two short button presses exit the PWM
tool. 

+ Square Wave Signal Generator

The signal generator creates a square wave signal with variable frequency up
to 1/4 of the MCU clock rate (2 MHz for 8 MHz MCU clock). The default frequency
is 1000 Hz and you can change it by turning the rotary encoder, The turning
velocity determines the frequency change, i.e. slow turning results in small
changes und fast turning in large changes. Since the signal generation is
based on the MCU's internal PWM mode you can't select the frequency
continuously, but in steps. For low frequencies the steps are quite small,
but for high frequencies they become larger and larger. A long button press
sets the frequency back to 1 kHz, and two brief button presses exit the
signal generator, as usual.

Pinout for signal output via probes:
  Probe #2:         output (with 680 Ohms resistor to limit current)
  Probe #1 and #3:  Ground

Hint: Rotary encoder or other input option required!

+ Zener Tool (hardware option)

An onboard DC-DC boost converter creates a high test voltage (up to 50 V) for
measuring the breakdown voltage of a Zener diode connected to dedicated probe
pins. While the test button is pressed the boost converter runs and the tester
displays the current voltage. After releasing the test button the minimum
voltage measured is shown when the test button was pressed long enough for a
stable test voltage. You may repeat this as long as you like. :) To exit the
Zener tool press the test button twice quickly.

The boost converter can also be driven by a dedicated I/O pin for a longer
battery life (ZENER_SWITCHED).

If your tester has just a 10:1 voltage divider without a boost converter for
measuring an external voltage, or the boost converter runs all the time, you
can choose an alternative mode (ZENER_UNSWITCHED) which measures the voltage
periodically without pressing the test button. When you see the cursor at the
bottom right between measurements you can exit the Zener tool by two short
presses of the test button.

There's another option to run the Zener check during normal probing (
HW_PROBE_ZENER). When no component is found at the standard probes the tester
will check for a voltage at the Zener probes. This option is only available
when either ZENER_UNSWITCHED or ZENER_SWITCHED is enabled.

In case your tester has a non-standard voltage divider (not 10:1) enable
ZENER_DIVIDER_CUSTOM and specify the resistor values (ZENER_R1 and ZENER_R2).

How to connect the Zener diode:
   Probe +: cathode
   Probe -: anode

+ Logic Probe (hardware option)

The logic probe checks the state of logic signals by using a dedicated ADC
input with a voltage divider frontend. The voltage divider should be 4:1 to
support voltages up to 20 V (for 15 V CMOS). The ADC pin is TP_LOGIC (in
config_<MCU>.h) and the voltage divider is set in config.h (LOGIC_PROBE_R1
and LOGIC_PROBE_R2). It might be a good idea to add some additional input
protection, such as a pair of clamping diodes.

After starting, the tester automatically reads the voltage, compares the
voltage with logic level thresholds and displays the logic level plus the
voltage:
  - 0 for low
  - 1 for high
  - Z for undefined/HiZ

In case a buzzer is available you'll also get an audible feedback:
  - low         active buzzer: short beep
                passive buzzer: short low frequency beep
  - high        active buzzer: long beep
                passive buzzer: short high frequency beep
  - undefined   silence / no beep

For setting the logic family and Vcc/Vdd or the logic level thresholds
there's a simple menu. Use the test push button to select a specific setting (
marked by an asterisk). Then use the rotary encoder to change the setting.
When changing the logic family and Vcc/Vdd the logic level thresholds are
automatically set to default values. After that you can adjust the thresholds
if needed. In case of a non-standard Vcc/Vdd choose the next higher one and
adjust the thresholds. The standard Vcc/Vdd values are:
  - TTL  : 5 V
  - CMOS : 3.3 V, 5 V, 9 V, 12 V, 15 V

And as usual, two short button presses will exit the logic probe.

Voltage divider frontend:

  Signal +
         |
         |
         -
        | | R1
        | | 10k
        | |
         -
         |
         |
         x----- TP_LOGIC 
         |      (ADC pin)
         |
         -
        | | R2
        | | 3k3
        | |
         -
         |
         |
     Gnd -

+ Continuity Check (hardware option)

This tool checks for continuity of a circuit and gives you an audible feedback
by a buzzer while also displaying the voltage across the probes. The test
current is limited by Rl (680 Ohms) to about 7 mA. The thresholds for the
audible feedback are:
  - < 100 mV     active buzzer: continuous beep
                 passive buzzer: repeating high frequency beep
  - 100-700 mV   active buzzer: repeating short beep
                 passive buzzer: repeating low frequency beep
  - > 700 mV     silence / no beep

The short beep is meant to indicate a possible semiconductor junction.
For an open circuit or a very high resistance the voltage will be near 5 V.

After starting the continuity check the tester displays the probe pinout for
a few seconds which can be skipped by pressing the test button. And two short
button presses will end the check.

Pinout for probes:
  Probe #1:  Vcc (with 680 Ohms resistor to limit current)
  Probe #3:  Ground

+ ESR Tool

The ESR tool measures capacitors in-circuit and displays the capacity and ESR
if the measurement detects a valid capacitor. Make sure that the capacitor is
discharged before connecting the tester! Values could differ from the standard
measurement (out-of-circuit) because any component in parallel with the
capacitor will affect the measurement.

For triggering a measurement please press the test key. Two quick short key
presses will exit the tool.

How to connect the capacitor:
   Probe #1: positive
   Probe #3: negative (Gnd)

+ Capacitor Leakage Check

The cap leakage check charges a cap and displays the current and the voltage
across the current shunt. It starts charging the cap using Rl (680 Ohms) and
switches to Rh (470 kOhms) when the current drops below a specific threshold.
As soon as the voltage has reached its minimum and doesn't change anymore the
displayed current is the leakage current.

Each cycle begins with the display of the pinout. After connecting the cap
press the test button (or right turn in case of a rotary encoder) to start
the charging process. To end charging press the test button again and the
tester will discharge the cap while displaying its voltage until the voltage
drops below the discharge threshold. To exit the check press the test button
twice.

Hint: Pay attention to the polarity of polarized caps!

How to connect the capacitor:
   Probe #1: positive
   Probe #3: negative (Gnd)

+ R/C/L Monitors

The monitor tools measure continuously a passive component connected to
probes #1 and #3. After starting a monitor tool, the tester displays the probe
pinout for a few seconds which can be skipped by pressing the test button.

There's a delay of one or two seconds between measurements, indicated by a
cursor at the bottom right, during which you can exit the monitor by two short
presses of the test button.

Available monitors:
- R Monitor (resistance)
- C Monitor (capacitance plus optionally ESR)
- L Monitor (inductance)
- R/C/L Monitor (R plus optionally L, or C plus optionally ESR)
- R/L Monitor (resistance plus optionally inductance)

For the C and L monitors there are options to auto-hold the last valid
measurement value (SW_MONITOR_HOLD_ESR, SW_MONITOR_HOLD_L). The last result
is displayed in the third text line.

Hint:
- The capacitance values for electrolytic caps can be a bit lower than in
  the normal probing cycle (caused by the repeating measurements with a DC
  signal).

+ LC Meter (hardware option)

The LC Meter hardware option is based on a simple LC oscillator circuit used
by various inexpensive PIC LC meters. The common design (82 µH and 1 nF) has
a base frequency of around 595 kHz, and connecting an additional capacitor or
inductor will decrease that frequency. With the help of a reference capacitor
with a known value, the measured frequencies and some math the value of the
unknown capacitor/inductor can be calculated.

The PIC LC meters usually have measurement ranges of 10 nH to 100 mH, and
0.1 pF to 900 nF. They seem to use a gate time of 100 ms for the frequency
counter. The m-firmwmare uses auto-ranging with gate times of 100 ms and
1000 ms to improve the resolution for low value L/Cs. Thus the ranges start at
about 1 nH and 10 fF (0.01 pF). The maximum inductance supported is roughly
150 mH. Regarding capacitance I've run into an issue with the circuit. At
around 33 nF the output signal starts having some spurs in the rising and
falling edges causing the frequency counter to see more pulses than there
really are. A user noted that this is a known problem of the LM311 based LC
oscillator circuit. After trying a few modifications without ponderable
success a second comparator or a Schmitt trigger logic gate seem to be the
best choice to clean up the signal of the oscillator output. The CMOS quad
NAND 4093 works fine for that. With a clean output signal the maximum
capacitance is around 120 nF (beyond that the LC oscillator becomes unstable).
The tester enforces a lower frequency limit of 10 kHz, i.e. the maximum values
are theoretically 250 mH or 3.5 µF if the LC oscillator would run stable.

When starting the LC Meter the tester will run a self-adjustment indicated
by an "adjusting..." message. After that you can connect the capacitor or
inductor you like to check. A short button press switches between C and L
measurement modes (default mode is C). The frequency of the LC oscillator
drifts over time (up to 100 Hz) and needs a re-adjustment. If you see an
increasing zero value or a "-" without any component connected please run
the self-adjustment by a long key press. If there's any problem with the
self-adjustment or you abort it by pressing some button the tester will exit
the LC meter and report an error. Two short button presses will end the
LC Meter tool.

Hints:
- The reference cap should be a low tolerance 1 nF film cap. You can also use
  any common film cap around 1 nF, measure its capacitance with a proper LCR
  meter, and update LC_METER_C_REF.
- If you're interested in the LC oscillator's frequency and its drifting
  enable LC_METER_SHOW_FREQ.

+ Frequency Counter (hardware option)

There are two versions of the frequency counter. The basic one is a simple
passive input for the T0 pin of the MCU. The extended version has an input
buffer, two oscillators for testing crystals (low and high frequency) and
an additional prescaler. The circuit diagrams for both are depicted in
Karl-Heinz' documentation.

- Basic Counter

With the basic frequency counter hardware option installed you can measure
frequencies from about 10 Hz up to 1/4 of the MCU clock with a resolution
of 1 Hz for frequencies below 10 kHz. The frequency is measured and displayed
continuously until you end the measurement by two short key presses. The
autoranging algorithm selects a gate time between 10 ms and 1000 ms based on
the frequency. The TO pin can be shared with a display.

- Extended Counter

The extended frequency counter has an additional prescaler and allows to
measure higher frequencies. The theoretical upper limit is 1/4 of the MCU's
clock rate multiplied by the prescaler (16:1 or 32:1). The control lines
are configured in config_<MCU>.h, and don't forget to set the correct
prescaler in config.h.

The input channel (buffered input, low frequency crystal oscillator, high
frequency crystal oscillator) is changed by pressing the test push button or
turning the rotary encoder. And as always, two short button presses will exit
the frequency counter.

+ Ring Tester (hardware option)

The ring tester (LOPT/FBT tester) check chokes and transformers for shorts.
The frontend creates a trigger pulse and the tester simply counts the number
of rings which corresponds to the Q value. The frontend can be driven by a
dediated pin (RING_TESTER_PIN) or via the probes (RING_TESTER_PROBES). In
either case the ATmega's TO pin is the counter input (counts on falling edge).
The TO pin can be also shared with a display.

After starting the ring tester the pinout of the probes is shown if the control
output via probes is enabled. Then the tester automatically checks the choke
or transformer and diplays the number of rings. As usual two short key presses
will end the test.

Interpretation of the number of rings for the frontend circuit with the
Darlington stage based on Bob Parker's ring tester:

  rings      Q
  -------------------------------
  0          short or open
  1 - 3      low Q (bad)
  4 - 5      medium Q (unclear)
  >= 6       high Q (good)

Besides the simple frontend mentioned above you can use also more sophisticated
circuits as long as they run with about 5 V, have a low current consumption (
< 20 mA) and generate a counter signal with falling edge.

Pinout for control output via probes:
  Probe #1:  Vcc (5 V)
  Probe #2:  pulse output (with 680 Ohms resistor to limit current)
  Probe #3:  Ground
  T0:        counter input

+ Event Counter (hardware option)

The event counter uses the T0 pin as dedicated input and is trigged by the
rising edge of a signal. The T0 pin can't be shared with a display. Adding
a simple input stage is recommended.

The counter is controlled by a small menu which also displays the counter
values.  Menu items are selected by a short key press and settings are changed
by the rotary encoder or additional keys. The first item is the counter mode:

  - Count    count time and events
  - Time     count events for a given time period
  - Events   count time for a given number of events

The second item "n" is the number of events. In the events mode it will show
the trigger threshold which can be changed. A long key press resets the
threshold to a default value (100). In other counting modes this item is
blocked. The next item "t" is the time period in seconds. Same story, only
for the time mode (default value: 60 s). And the last item starts or stops
counting by a long key press. When the counter runs the counted events and
time elapsed are updated each second, and after stopping the results are
displayed.

The limit for the time period is 43200 s (12 h) and for the events it's
4*10^9. If any of those limits is exceeded the counting is automatically
stopped. The event limit or threshold (when in events mode) is checked every
200 ms. Therefore some overshoot may occur in case of more than 5 events/s.

- Trigger Output

Optionally you can enable a trigger output (EVENT_COUNTER_TRIGGER_OUT) to
control some other device using the probes. The trigger output is set high
while counting, i.e. rising edge at start and falling edge at stop.

Pinout for trigger output via probes:
  Probe #1:    Ground
  Probe #2:    Output (with 680 Ohms resistor to limit current)
  Probe #3:    Ground

+ Rotary Encoder

This test checks rotary encoders while determining the pin-out. Your job is
to connect the probes to the A, B and Common pin and to turn the encoder
a few steps clockwise. The algorithm needs four greycode steps to determine
the proper function and pin-out. The turning direction is important to
distinguish the A nd B pins, because reversed pins cause a reversed direction.

When a rotary encoder is detected the tester will display the pin-out and
wait for a key press (or a moment for continuous mode) before resuming testing.
To exit the rotary encoder test please press the test push button once while
testing.

+ Contrast

You can adjust the contrast for some graphic LCD modules. A short key press
increases the value and and a long key press decreases it. Two short key
presses will exit the tool. With a rotary encoder installed the value
can also be adjusted by turning the encoder.

+ IR RC Detector/Decoder

This function detects and decodes signals from IR remote controls, and
requires an IR receiver module, for example the TSOP series. When compiling
the firmware you can choose between two variants how the IR receiver module is
connected to the tester. The first one is to connect the IR module to the
standard testpins (SW_IR_RECEIVER). The second one is a fixed IR module
connected to a dedicated MCU pin (HW_IR_RECEIVER).

If a known protocol is detected the tester displays the protocol, address
(when available), command, and in some cases optional data in hexadecimal.
The format is:
  <protocol> <data field(s)>

For a malformend packet a "?" is shown as data field.

For a unknown protocol the tester displays the number of pauses and pulses,
the duration of the first pulse and the first pause in units of 50µs:
  ? <pulses>:<first pulse>-<first pause>

When the number of pulses stays the same for different buttons of the RC, the
modulation is most likely PDM or PWM. A changing number of pulses indicates
bi-phase modulation.  

To exit the tool please press the test key.

Supported protocols and their data fields:

  - JVC
    <address>:<command>

  - Kaseikyo (aka Japanese Code, 48 bits)
    <manufacturer code>:<system>-<product>:<function>

  - Matsushita (Panasonic MN6014, C6D6 / 12 bits)
    <custom code>:<data code>

  - Motorola
    <command>

  - NEC (standard & extended)
    <address>:<command>
    R for repeat sequence

  - Proton / Mitsubishi (M50560)
    <address>:<command>

  - RC-5 (standard)
    <address>:<command>

  - RC-6 (standard)
    <address>:<command>

  - Samsung / Toshiba (32 bits)
    <custom code>:<data code>

  - Sharp / Denon
    <address>:<command>

  - Sony SIRC (12, 15 & 20 bits)
    12 & 15: <command>:<address>
    20:      <command>:<address>:<extended>

Optional protocols (SW_IR_RX_EXTRA):

  - IR60 (SDA2008/MC14497)
    <command>

  - Matsushita (Panasonic MN6014, C5D6 / 11 bits)
    <custom code>:<data code>

  - NEC µPD1986C
    <data code>

  - RECS80 (standard & extended)
    <address>:<command>

  - RCA
    <address>:<command>

  - Sanyo (LC7461)
    <custom code>:<key>

  - Thomson
    <device>:<function>

The carrier frequency of the TSOP receiver module doesn't have to match the RC
exactly. A mismatch reduces the maximum distance, but that doesn't matter much
for this application.

With the buzzer harwdare option you can enable a short confirmation beep for
valid data frames/packets (SW_IR_RX_BEEP).

- IR receiver module connected to probes

Please connect the IR receiver module after entering the IR detector function.

How to connect the TSOP module (default pinout SW_IR_RX_PINOUT_G_V_D):
  Probe #1:  Gnd
  Probe #2:  Vs (current limited by 680 ohms resistor)
  Probe #3:  Data/Out

The firmware can be configured to use an alternative pinout if necessary,
expecially useful for testers with a ZIF socket:
  - alternative pinout SW_IR_RX_PINOUT_D_G_V
    Probe #1:  Data/Out
    Probe #2:  Gnd
    Probe #3:  Vs (current limited by 680 ohms resistor)
  - alternative pinout SW_IR_RX_PINOUT_D_V_G
    Probe #1:  Data/Out
    Probe #2:  Vs (current limited by 680 ohms resistor)
    Probe #3:  Gnd

Hint:
  The current limiting resistor for Vs implies an IR receiver module with a
  supply voltage range of about 2.5 to 5 V. If you have a 5 V only module you
  can disable the resistor in the config.h file on your own risk. Any short
  circuit may destroy the MCU.

- Fixed IR receiver module

For the fixed IR module please set the port and pin used in config_<MCU>.h

+ IR RC Transmitter

The IR RC transmitter sends RC codes you've entered, and is meant to check
IR RC receivers or remote controlled devices. This tool requires additional
keys, such as a rotary encoder, a display with more than 4 lines, and a simple
driver circuit for the IR LED.

The display shows you the protocol, the carrier frequency, the duty cycle of
the carrier and a few data fields. By a short press of the test button you
switch between the items. The selected item is indicated by an '*'. Use the
rotary encoder (or other input option) to change the setting/value of an item.
A long press of the test button and the tester sends the IR code as long as
you keep the button pressed. And as usual, two short presses exit the tool.

When you change the protocol the carrier frequency and duty cycle are set to
the protocol's default values. But you can change them if you wish. The carrier
frequency can be set to 30 up to 56 kHz and the duty cycle to 1/2 (50 %),
1/3 (33 %) or 1/4 (25 %). The data fields are the user settable parts of the
IR code and are explained later on. In most cases it's just the address and
the command.

Supported protocols and their data fields:

  - JVC
    <address:8> <command:8>

  - Kaseikyo (Japanese Code)
    <manufacturer code:16> <system:4> <product:8> <function:8>

  - Matsushita (Panasonic, MN6014 12 bits)
    <custom code:6> <key data:6>

  - Motorola
    <command:9>

  - NEC Standard
    <address:8> <command:8>

  - NEC Extended
    <address:16)> <command:8>

  - Proton / Mitsubishi (M50560)
    <address:8> <command:8> 

  - RC-5 Standard
    <address:5> <command:6>

  - RC-6 Standard, Mode 0
    <address:8> <command:8>

  - Samsung / Toshiba (32 bits)
    <custom code:8> <key data:8>

  - Sharp / Denon
    <address:5> <command:8> <mask:1>

  - Sony SIRC-12
    <command:7> <address:5>

  - Sony SIRC-15
    <command:7> <address:8>

  - Sony SIRC-20
    <command:7> <address:5> <extended:8>

Optional protocols (SW_IR_TX_EXTRA):

  - Thomson
    <device:4> <function:7>

The data fields are separated by spaces and their syntax is:
  <field name>:<number of bits>

Pinout for signal output via probes:
  Probe #2:         signal output (with 680 Ohms resistor to limit current)
  Probe #1 and #3:  Ground

The signal output (probe #2) has a current limiting resistor and can drive an
IR LED with only about 5 mA directly, which isn't sufficient for the IR LED's
typical rating of 100 mA. Therefore you need a simple driver circuit based on
a switching transistor, the IR LED and a current limiting resistor for the LED.

Example for driving an IR LED (Vf 1.5 V, If 100 mA) with about 50 mA:

                           + +5V
                           |
                           |
                           -
                          | |
                       75 | |
                          | |
                           -
                           |
                           |
                          ___ ->
                   IR LED \ / ->
                          ---
                           |
                           | C
              -----    B |/
  Signal ----| 3k9 |-----|  NPN
              -----      |\
                           | E
                    BC548  |
                           |
                           - Gnd

Hint:
  If the pulse/pause timing is incorrect please activate the alternative delay
  loop method SW_IR_TX_ALTDELAY. This may be required when the C compiler
  optimizes the standard delay loop despite specific statements to keep the
  inline Assembler code.

+ Opto Coupler Tool

This tool checks opto couplers and shows you the LED's V_f, the CTR (also If),
and t_on/t_off delays (BJT types). It supports standard NPN BJTs, NPN 
Darlington stages and TRIACs. For the CTR measurement the MCU's I/O pin is
overloaded for about 3 ms. The datasheet specifies a maximum output current of
20 mA, but we overload the I/O pin up to about 100 mA. Therefore the maximal
CTR value is limited and any CTR over 2000 % should be considered with caution.

The maximum drive current for the LED is about 5 mA, which should be considered
for TRIAC types. Relay types (MOSFET back to back) are detected as BJT and the
CTR will be meaningless. Types with anti-parallel LEDs are ignored.

For testing you need a simple adapter with following three test points:

BJT type:
- LED's anode
- LED's cathode and BJT's emitter connected together
- BJT's collector

TRIAC type:
- LED's anode
- LED's cathode and TRIAC's MT1 connected together
- TRIAC's MT2

You may connect the adapter any way to the three probes of the component
tester. It will detect the pinout automatically.

After entering the tool please connect the adapter and press the test key
briefly to scan for an opto coupler. If one is found the tester displays
the type and various details. Or it displays "none" when no opto coupler was
detected. A blinking cursor indicates that you have to press the test key
(or turn the rotary encoder) for a new scan. Two short key presses end the
tool as usual.

+ Photodiode Check

This check allows you to monitor the current of a photodiode. At first the
tester displays the probe pinout for a few seconds (can be ended by a short
button press). Then it switches to monitoring the current I_P with the diode
in reverse-bias (photoconductive) mode, noted by 'rev'. A short button press
changes the bias to no-bias (photovoltaic) mode, noted by 'no'. Another button
press changes the mode back again. And as you've already guessed, two short
button presses end the check function.

For checking the photodiode you could cover it with your hand or use an
appropriate light source at different distances. Less light results in less
current, and vice versa. The tester might pick up some EMI causing a low
current, especially in reverse-bias mode. You can see that when no photodiode
is connected. Also remember that photodiodes in reverse-bias mode have a dark
current.

Warning:
  Don't check solar cells!

Pinout for probes:
  Probe #1:    Anode 
  Probe #3:    Cathode

+ Diode/LED Quick-Check

The quick-check looks continuously for a diode or LED connected to probes #1
and #3. It's meant to quick-check diodes/LEDs and to determine their polarity.
LEDs will blink while being checked.

After starting, the tester displays the probe pinout for a few seconds which
can be skipped by pressing the test button. When a diode or LED is found its
pinout and Vf are shown. The anode pin will be always on the left, and the
cathode pin on the right. In case of two anti-parallel diodes/LEDs the second
one is also displayed. You know the drill, two short button presses end the
quick-check.

+ Servo Check

This function outputs a PWM signal for RC servos which are driven by a 1-2 ms
PWM pulse. It supports the typical PWM frequencies of 50, 125, 250 and 333 Hz
while the pulse length can be between 0.5 and 2.5 ms. There is also a sweep
mode for sweeping between 1 and 2 ms pulse length with an adjustable sweep
speed.

Please adjust the pulse width with the rotary encoder. Clockwise for a longer
pulse, and counter-clockwise for a shorter pulse. A long button press resets
the pulse to 1.5 ms.  

You can switch between pulse and frequency selection mode with a short button
press (mode marked by an asterisk). When in frequency selection mode use the 
rotary encoder to choose the PWM frequency. A long button press enables or
disables the sweep mode (marked by a "<->" after the frequency).

As long as the sweep mode is enabled, the pulse selection is replaced by the
sweep period. The rotary encoder allows you to change the period. 

As usual, two short button presses exit the function.

Pinout for signal output via probes:
  Probe #2:         PWM output (with 680 Ohms resistor to limit current)
  Probe #1 and #3:  Ground

Hint: You have to provide an additional power supply for the servo.

Some pinouts of typical 3pin servo connectors:

Vendor         pin 1               pin 2               pin 3
---------------------------------------------------------------------- 
Airtronics     PWM White/Black     Gnd Black           Vcc Red
Futaba         PWM White           Vcc Red             Gnd Black
hitec          PWM Yellow          Vcc Red             Gnd Black
JR Radios      PWM Orange          Vcc Red             Gnd Brown

+ OneWire Scan

The scanning tool for OneWire lists the ROM codes of all connected devices.
Please see section "Busses & Interfaces" for the setup of the OneWire bus.
When using the probes the tester will inform you about the pin assignment and
waits until it detects the external pull-up resistor. You can skip this by a
key press.

Each time you press the test button the tester will scan for the next device
and display its ROM code (in hexadecimal). The first part of the output is
the devices' family code and the the second part is its serial number. The
CRC is omitted. A family code >= 0x80 (bit #7 set) indicates a customer
specific code and the upper (left) three hexadecimal digits of the serial
number are the customer's ID.

After the last device is found the tester will let you know. It will also
inform you about CRC and bus errors. In case of a finished scan or bus error
you can start a completely new scan process by pressing the test button.  
And as usual, two short button presses will exit the tool.

+ DS18B20/DS18S20 Temperature Sensors

This tool reads the OneWire temperature sensor DS18B20/DS18S20 and displays
the temperature. Please see section "Busses & Interfaces" for the setup of the
OneWire bus. When using the probes the tester will inform you about the pin
assignment and then waits until it detects the external pull-up resistor. You
can skip this by a key press.

After connecting the DS18B20/DS18S20 as the only client on the OneWire bus
push the test button for reading the sensor (this may take nearly a second).
To exit the tool press the test button twice quickly. With a long button press
you can select the auto mode (automatic updating) which is indicated by an "*"
after the tool name. Another long button press switches back to the manual
mode.

Pin assignment for probes:
  Probe #1:  Gnd
  Probe #2:  DQ (data)
  Probe #3:  Vcc (current limited by 680 ohms resistor)
  An external pull-up resistor of 4.7 kOhms between DQ and Vcc is required!

Hints:
- Option for DS18B20: round to 0.1 °C/F (UI_ROUND_DS18B20)
- Option for DS18S20: high resolution (DS18S20_HIGHRES)
- The DS18B20 tool can also read the sensor DS1822.

+ DHTxx Temperature & Humidity Sensors

Tool for reading DHT11, DHT22 and compatible temperature & humidity sensors.
First the tester displays the pinout and then waits for the external pull-up
resistor. After that it shows the selected sensor type (default: DHT11) and
a short press of the test button reads the sensor. On a successful read the
tester outputs the measured values, on any error the result will be a "-".
A long button press changes the sensor type, and two short button presses
exit the tool. When changing the sensor you also have the option to activate
automatic reading (each second) which is indicated by an "*" after the sensor
name.

Supported sensors:
  DHT11: DHT11, RHT01
  DHT22: DHT22, RHT03, AM2302
         DHT21, RHT02, AM2301, HM2301
         DHT33, RHT04, AM2303
         DHT44, RHT05

Pin assignment for probes:
  Probe #1:  Gnd
  Probe #2:  Data
  Probe #3:  Vdd (current not limited)

An external pull-up resistor of 4.7 kOhms between Data and Vdd is required!
Some sensor modules include already a 10 kOhms pull-up resistor which works
also fine with short cables.

Hint:
  Because of the sensor's power demand the 680 Ohms test resistor can't be
  used to limit current. Be aware that any short circuit may destroy the MCU.

+ MAX6675/MAX31855 Thermocouple Converters

Both MAX are thermocouple converters with cold-junction compensation and are
controlled via the SPI bus. MAX6675 is just for K type thermocouples, while
there are several versions of the MAX31855 for different thermocouple types.
MAX31855 has a Vcc of 3.3 V and therefore requires level shifters.

The operation of both MAX is identical. By pressing the test button a new
measurement is triggered and the temperature will be displayed. On any error
a "-" is shown instead. For automatic reading every second you can enable
the auto-mode by a long press of the test button, indicated by an "*" in after
the MAX's name. A second long key press disables the auto-mode. Two short key
presses will end the tool.

Hints:
- Customize MAX31855_CS in config_<MCU>.h!
- You also need SPI read support (SPI_RW).

+ BH1750 Ambient Light Sensor

The BH1750 is an inexpensive ambient light sensor with an I2C bus and a 3.3 V
operating voltage. With a 3.3 V voltage regulator and pull-up resistors for SCL
and SDA (to 3.3 V) is can be usually connected directly to an 5 V ATmega, when
other I2C ICs on the bus don't cause any issues. Otherwise you'll need a level
shifter.

A short button press starts a new measurement. Alternatively, a long button
press switches to the automatic mode (indicated by an '*' in the first line),
and also back again. In the automatic mode the tester runs a measurement every
second. In case of an error the tester displays a '-' instead of the light
intensity. And as usual, two short key presses will end the tool.

Hints:
- BH1750 modules usually come with a 3.3 V LDO and 4.7 kOhms pull-up
  resistors (to 3.3 V) for SCL and SDA.
- An 'error' directly after starting indicates a sensor issue, e.g. no I2C
  communication.

+ INA226 Power Monitor

The INA226 is a power monitor with an I2C interface, usually run at 3.3 V or
5 V. It measures the load's voltage (VBUS, referenced to Gnd) and the voltage
across a current shunt (VIN+ and VIN-). If you power the INA226 by 3.3 V and
have pull-up resistors for SCL and SDA to 3.3 V in place it should work fine
with the 5V ATmega when the bus isn't shared with other 5V I2C ICs. Otherwise
you'll need a level shifter.

A short button press starts a new measurement. Alternatively, a long button
press switches to the automatic mode (indicated by an '*' in the first line),
and also back again. In the automatic mode the tester runs a measurement every
second. In case of an error the tester displays a '-' instead of the
measurement values. And as usual, two short key presses will end the tool.

Common setups:

  low-side shunt    high-side shunt #1    high-side shunt #2
 
  V_PSU    INA226   V_PSU    INA226       V_PSU    INA226
    |                 |                     |
    +----- VBUS       +----- VBUS           +----- VIN+
    |                 |      & VIN+         |
  load              shunt                 shunt
    |                 |                     |
    +----- VIN+       +----- VIN-           +----- VIN-
    |                 |                     |      & VBUS
  shunt             load                  load
    |                 |                     |
    +----- VIN-       +----- Gnd            +----- Gnd
    |                 |                     |
   Gnd               Gnd                   Gnd

For the low-side and high-side #1 setups the voltage across the current shunt
impacts VBUS and you'll need to enable INA226_MINUS_SHUNT for compensation.
For the high-side #2 setup the shunt voltage can be ignored.

Because of the high resolution of the shunt voltage measurement of 2.5 µV the
wiring and environment (EMI) have a high impact when measureing low currents
around 0 A, causing broadly changing current values. To mitigate this you can
enable and set a zero threshold (INA226_SHUNT_ZERO_THRESHOLD), i.e. any value
less than or equal to the threshold is considered to be zero. The zero
threshold is set as the ADC's raw value of the voltage across the current
shunt and includes also the negative span (1: +/- 2.5 µV, 2: +/- 5 µV,
3: +/- 7.5 µV, ...).

Another feature of the INA226 is an integrated averaging of measurements which
can be configured (INA226_SAMPLES). The average is calculated from a given
number of samples which can be 1 (no average), 4, 16, 64, 128, 512 or 1024.

If you have the buzzer option you can also enable a power alarm feature (
INA226_POWER_ALARM) which will sound the buzzer briefly when a specific power
threshold is exceeded. The power threshold is set in mW.

Hints:
- An "error" directly after starting indicates a sensor issue, e.g. no I2C
  communication.
- The maximium for V_PSU is 36 V. 

+ Flashlight

This is a general purpose switched output for controlling some additional
circuitry, such like an LED flashlight. The tester simply toggles the
output pin between low and high each time this function is run. Loads lower
than 20 mA can be driven directly.

+ Voltmeter 0-5 V DC

A simple voltmeter for DC voltages from 0 to 5 V with two selectable input
impedances (high: 470 kOhms, low: 700 Ohms). After displaying the obligatory
probe pinout, which can be skipped by pressing the test button, the
measurement starts in the high input impedance mode (indicated by an 'H' in
the first line). With a long button press you switch to the low impedance
mode (indicated by an 'L'), and also vice versa.

Additional functionality is available when a buzzer is installed. If a
specific threshold is exceeded the tester will sound a short beep. A short
button press enables this function, which is indicated by displaying the
threshold voltage in braces in the second line (right of the measured voltage).
Another short button press disables the function again. If you also have
a rotary encoder (or any other input option) the threshold can be changed in
0.1 V steps by turning the encoder left (decrease) or right (increase).

Last, but not least, two short button presses exit the voltmeter.

Pin assignment for probes:
  Probe #1:  positive
  Probe #3:  negative

Warnings:
- No input protection! Only for DC voltages from 0 to 5 V!
- No reverse polarity protection! Be extra careful!

+ Self Test

If you start the self-test via the menu you'll be asked to short circuit all
three probes and the tester will wait until you have. In case of any problem
you can abort that by a key press. That will also skip the complete self-test.

The self-test function runs each test just 5 times. You can skip a test by a
short key press or skip the entire self-test by a long key press.

In test #4 you have to remove the short circuit of the probes. The tester will
wait until you removed the short circuit.

The test steps are:
- T1: internal bandgap reference (in mV)
      should be 1000 - 1200 mV
- T2: comparison of Rl resistors (offset in mV)
      should be close to 0 mV (usually within +/- 10 mV)
- T3: comparison of Rh resistors (offset in mV)
      should be close to 0 mV (usually within +/- 10 mV)
- T4: remove short circuit of probes
- T5: leakage check for probes in pull-down mode (voltage in mV)
      should be close to 0 mV (usually within 3 mV)
- T6: leakage check for probes in pull-up mode (voltage in mV)
      should be close to Vcc (usually within 10 mV)

Hints:
- Run the self-test with the ISCP/ISP cable removed!
- When the T2 values differ by more than 5 mV between probe pairs there could
  be a mismatch of the Rl test resistors.
- The same for T3 values and Rh test resistors.
- Long test leads have a negative impact and worsen the values in T2, T3, T5
  and T6.
- Strange values are typically a sign of shot MCU pins, shorts, dirty PCB
  and bad contact issues.

+ Self Adjustment

The self-adjustment measures the resistance and the capacitance of the probe
leads, i.e. the PCB, internal wiring and probe leads as a sum, for creating
a zero offset. It also measures the internal resistance of the MCU port pins
in pull-down and pull-up mode. If the tests are skipped or strange values are
measured the default values defined in config.h are used. If everything went
fine the tester will display and use the new values gained by the self
adjustment (they will be not stored automatically in the EEPROM, see
"Save/Load" below).

The voltage offset of the analog comparator is automatically adjusted by the
capacitance measurement (in normal probing mode, outside of the self
adjustment) if the capacitor is in the range of 100 nF up to 3.3 µF. Also the
offset of the internal bandgap reference is determined in the same way.

Before running the self-adjustment the first time, please measure a film
capacitor with a value between 100 nF and 3.3 µF three times at least to let
the tester self-adjust the offsets mentioned above. Typically the first
measurement will result in a slightly low value, the second in a high one
and the third will be fine. This is caused by the self adjusting offsets.
Both offsets are displayed at the end of the self-adjustment.

With a fixed cap for self-adjustment the automatic offset handling in the
capacitance measurement is replaced by a dedicated function run during the
self-adjustment procedure. So you don't have to measure a film cap before
that. 

In case the capacitance offsets vary across the probe pairs you can enable
probe pair specific offsets in config.h (CAP_MULTIOFFSET). The same is
possible for resistance offsets (R_MULTIOFFSET).

The self-adjustment is very similar to the self-test regarding the procedure
and user interface.

The adjustments steps are:
- A1: offsets for bandgap reference and analog comparator
      (only for fixed cap option)
- A2: resistance of probe leads/pins (in 10 mOhms)
- A3: remove short circuit of probes
- A4: MCU's internal pin resistance for Gnd (voltage across RiL)
- A5: MCU's internal pin resistance for Vcc (voltage across RiH)
- A6: capacitance of probe leads/pins (in pF)

Limits:
- probe resistance   < 1.50 Ohms for two probes in series
- probe capacitance  < 100 pF
- IO pin's internal resistance in low mode (RiL)   < 25 Ohms
- IO pin's internal resistance in high mode (RiH)  < 29 Ohms

Hints:
- Run the self-adjustment with the ISCP/ISP cable removed!
- When the resistance values for the probe leads/pins vary too much,
  there could be a contact problem.
- If the capacitance offset (A6) is 0 it's most likely caused by a discharge
  issue (increase CAP_DISCHARGED).

Remember: Adjustment is not calibration! Calibration is the procedure to
compare measurement results with a known traceable standard and noting the
differences. The goal is to monitor the drift over time. Adjustment is the
procedure to adjust a device to meet specific specs.

+ Save/Load

After running the self-adjustment the "Save" function will update the
adjustment values stored in the MCU's EEPROM. The next time you power on the
tester the updated values (profile #1) will be loaded and used automatically.

For your convenience you can save and load two profiles, e.g. if you have
two different probe sets. In case you need more than two profiles you can
activate a third one (UI_THREE_PROFILES).

The idea of the save function is to prevent automatic saving of adjustment
values. If you need to use other probe leads for some tests, you'd simply
adjust the tester for the temporary probe leads and perform the tests. When
you switch back to the standard probe leads you don't need to re-adjust
the tester because the old values are still stored. Just powercycle the
tester.

There is an option (UI_CHOOSE_PROFILE) to automatically enter the load menu
after powering on the tester.

+ Show Values

This displays the current adjustment values and offsets used. The usage of an
external 2.5 V voltage reference is indicated by an '*' behind Vcc.

+ Font/Symbols

These menu items display all characters of the font or component symbols for
test purposes. Lines/blocks start with the hexadecimal address of the first
character/symbol in that line/block. Then followed by 8 characters or as much
symbols as fit in that block.

+ Power Off

This function will power off the tester if enabled by SW_POWER_OFF.

+ Exit

If you've entered the menu by mistake you can exit it by this command.

+ Order of Menu Items

The order of menu items is set by the firmware source code, but can be
changed. To do that open the file 'user.c' and look for function
PresentMainMenu(). Then scroll down to the section after the local variables,
starting with the comment 'set up menu'. For each menu item you'll see a short
code block. The order of the blocks determines the order of the menu items.
For changing the order simply rearrange the code blocks as you like.

* Resistors

Resistors are measured twice (both directions) and the values are compared.
If the values differ too much the tester assumes that there are two resistors
instead of just a single one. In that case the tester displays the result as
two resistors with the same pins, like "1 -- 2 -- 1", and the two different
resistance values. For resistors lower than 10 Ohms an extra measurement with
a higher resolution is performed. In some rare cases the tester might not be
able to detect a very low resistance. If that happens simply re-run the test.

For checking potentiometers or trimpots you can enable the additional output
of the total resistance (Rt) and the ratio of both resistors to the total
resistance (R1 and R2) in % (SW_R_TRIMMER).

When the optional check for E series norm values (SW_R_E*) is enabled the
tester takes the next lower and next higher norm value and compares them with
the measured resistance while also considering component tolerances. There are
two output modes. In the text mode the tester displays the E series and the
tolerance applied followed by matching norm values. A "-" indicates that no
norm value matches. In the color-code output mode the tester displays the
E series and the resistor's color code including the color band for tolerance.
Be aware that colors can differ with the display module and used color
combinations. If any color is off simply adjust the color value (COLOR_CODE_*)
in the file colors.h. An Internet search for "RGB565 tool" will list many
online tools for creating/picking RGB565 color values. Especially for
SMD resistors there's an additional output for the EIA-96 code (implies E96
1 %).

* Capacitors

The measurement of capacitance is split into three methods. Large caps > 47 µF
are measured by the charging cycle method with 10 ms pulses. Mid-sized
caps between 4.7 µF and 47 µF are processed the same way but with 1 ms charging
pulses. And small caps are done by the analog comparator method. That
way the accuracy of the measurement of caps is optimized.

Large capacitances require a correction. Without correction the measured values
are too large. IMHO, that is caused by the measurement method, i.e. the ADC
conversion after each charging pulse needs some time and the cap looses charge
due to internal leakage during the same time. Also the ADC conversion itself
needs some charge to operate. So it takes longer to charge the cap, and the cap
seems to have a larger capacitance. A discharge measurement later on tries to
compensate this, but is able to do it just partially. The correction factors (
CAP_FACTOR_SMALL, CAP_FACTOR_MID and CAP_FACTOR_LARGE in config.h) are choosen
to work with most tester models. In some cases you might have to change them.

A logic for preventing large caps to be detected as resistors was added.
Resistors < 10 Ohms are checked for being large caps.

A measured capacitance value more than 5 pF (incl. the zero offset) is
considered valid. Lower values are too uncertain and could be caused by
placing the probe leads a little bit differently and things like that.
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

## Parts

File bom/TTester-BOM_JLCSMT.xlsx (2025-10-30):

Comment | Designator | Footprint | LCSC Part #（optional）
16MHz | Y1 | Crystal_SMD_HC49-SD | C12676
TPMCP1702T-5002E/CB | U5 | SOT-23 | C3040636
LM4040DBZ-2.5 | U4 | SOT-23 | C9421
MT3608 | U3 | SOT-23-6 | C2932326
MCP73832-2-OT | U2 | SOT-23-5 | C38066
ATmega644PA-A | U1 | TQFP-44_10x10mm_P0.8mm | C38349
470R | R25 | R_0805_2012Metric | C17710
27k | R24,R23 | R_0805_2012Metric | C17593
100k | R22,R2 | R_0805_2012Metric | C149504
3k3 | R21 | R_0805_2012Metric | C26010
33k | R20 | R_0805_2012Metric | C17633
3k3 0.1% | R19 | R_0805_2012Metric | C2989690
10k 0.1% | R18 | R_0805_2012Metric | C5159707
1k | R17,R16 | R_0805_2012Metric | C17513
10k | R15,R14,R6,R1 | R_0805_2012Metric | C17414
470k 0.1% | R13,R11,R9,R7 | R_0805_2012Metric | C316216
680R 0.1% | R12,R10,R8 | R_0805_2012Metric | C2988999
2k2 | R5 | R_0805_2012Metric | C17520
15k | R4 | R_0805_2012Metric | C17475
180k | R3 | R_0805_2012Metric | C17501
MMBT3904 | Q4,Q3 | SOT-23 | C20526
MMBT3906 | Q2 | SOT-23 | C53444
DMP1045U | Q1 | SOT-23 | C177033
4.7uH | L1 | L_1206_3216Metric | C2941590
USB_C | J1 | USB_C_Receptacle_GCT_USB4125-xx-x-0190_6P_TopMnt_Horizontal | C283540
LED | D4,D3 | LED_0805_2012Metric | C84256
SS34 | D2,D1 | D_SMA | C8678
10u | C17,C15 | CP_EIA-3216-18_Kemet-A | C7171
10n | C14 | C_0805_2012Metric | C1710
4u7 | C13,C12,C3,C2,C1 | C_1206_3216Metric | C29823
100n 10% | C11 | C_0805_2012Metric | C476766
22p | C10,C9 | C_0805_2012Metric | C1804
1n | C8 | C_0805_2012Metric | C46653
100n | C7,C6 | C_0805_2012Metric | C49678
22u | C5,C4 | C_0805_2012Metric | C45783

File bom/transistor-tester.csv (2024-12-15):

Id | Designator | Footprint | Quantity | Designation | Supplier and ref
1 | J4 | DIP_Socket-14_W4.3_W5.08_W7.62_W10.16_W10.9_3M_214-3339-00-0602J | 1 | TEST
2 | Y1 | Crystal_SMD_HC49-SD | 1 | 16MHz
3 | U5 | SOT-23 | 1 | TPMCP1702T-5002E/CB
4 | U4 | SOT-23 | 1 | LM4040DBZ-2.5
5 | U3 | SOT-23-6 | 1 | MT3608
6 | U2 | SOT-23-5 | 1 | MCP73832-2-OT
7 | U1 | TQFP-44_10x10mm_P0.8mm | 1 | ATmega644PA-A
8 | TP3 | TestPoint_Pad_3.0x3.0mm | 1 | SMD_P3
9 | TP2 | TestPoint_Pad_1.5x1.5mm | 1 | SMD_P2
10 | TP1 | TestPoint_Pad_1.5x1.5mm | 1 | SMD_P1
11 | SW1 | RotaryEncoder_Alps_EC12E-Switch_Vertical_H20mm | 1 | Rotary Encoder
12 | R25 | R_0805_2012Metric | 1 | 470R
13 | R24,R23 | R_0805_2012Metric | 2 | 27k
14 | R22,R2 | R_0805_2012Metric | 2 | 100k
15 | R21 | R_0805_2012Metric | 1 | 3k3
16 | R20 | R_0805_2012Metric | 1 | 33k
17 | R19 | R_0805_2012Metric | 1 | 3k3 0.1%
18 | R18 | R_0805_2012Metric | 1 | 10k 0.1%
19 | R17,R16 | R_0805_2012Metric | 2 | 1k
20 | R15,R14,R6,R1 | R_0805_2012Metric | 4 | 10k
21 | R13,R11,R9,R7 | R_0805_2012Metric | 4 | 470k 0.1%
22 | R12,R10,R8 | R_0805_2012Metric | 3 | 680R 0.1%
23 | R5 | R_0805_2012Metric | 1 | 2k2
24 | R4 | R_0805_2012Metric | 1 | 15k
25 | R3 | R_0805_2012Metric | 1 | 120k
26 | Q4,Q3 | SOT-23 | 2 | MMBT3904
27 | Q2 | SOT-23 | 1 | MMBT3906
28 | Q1 | SOT-23 | 1 | DMP1045U
29 | L1 | L_1206_3216Metric | 1 | 4.7uH
30 | J7 | Waveshare_2.4_ILI9341_18366 | 1 | ILI9341 LCD
31 | J5 | TO-92L_Inline_Wide | 1 | 1x03 2.54
32 | J3 | PinHeader_2x03_P2.54mm_Vertical | 1 | ISP
33 | J2 | PinHeader_1x02_P2.54mm_Vertical | 1 | Battery Li-Po 3.7V
34 | J1 | USB_C_Receptacle_GCT_USB4125-xx-x-0190_6P_TopMnt_Horizontal | 1 | USB_C
35 | D4,D3 | LED_0805_2012Metric | 2 | LED
36 | D2,D1 | D_SMA | 2 | SS34
37 | C17,C15 | CP_EIA-3216-18_Kemet-A | 2 | 10u
38 | C14 | C_0805_2012Metric | 1 | 10n
39 | C13,C12,C3,C2,C1 | C_1206_3216Metric | 5 | 4u7
40 | C11 | C_0805_2012Metric | 1 | 100n 1%
41 | C10,C9 | C_0805_2012Metric | 2 | 22p
42 | C8 | C_0805_2012Metric | 1 | 1n
43 | C7,C6 | C_0805_2012Metric | 2 | 100n
44 | C5,C4 | C_0805_2012Metric | 2 | 22u

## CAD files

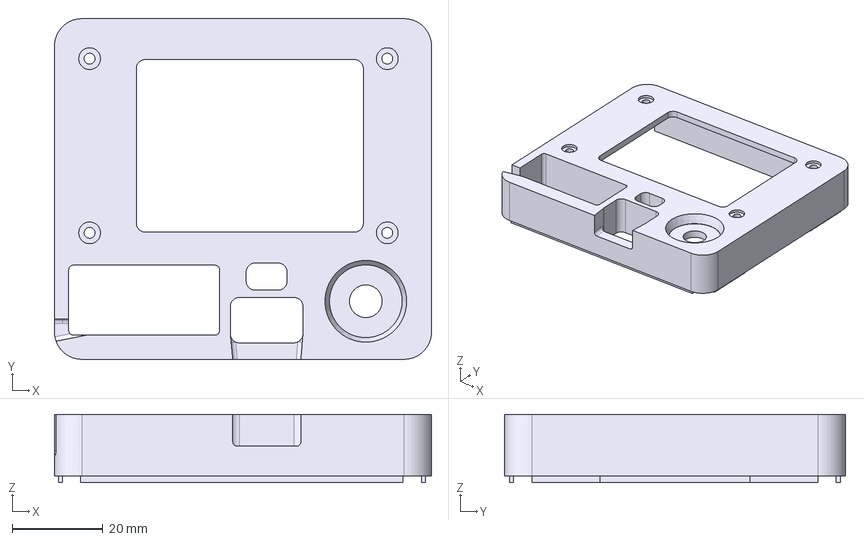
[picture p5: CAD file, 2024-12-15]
3d-enclosure/transistor-tester-top.step
83.0 x 75.0 x 15.0 mm

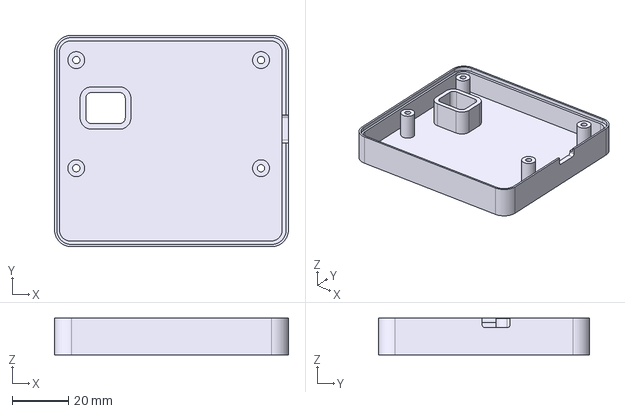
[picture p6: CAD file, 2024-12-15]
3d-enclosure/transistor-tester-bottom.step
83.0 x 75.0 x 13.0 mm

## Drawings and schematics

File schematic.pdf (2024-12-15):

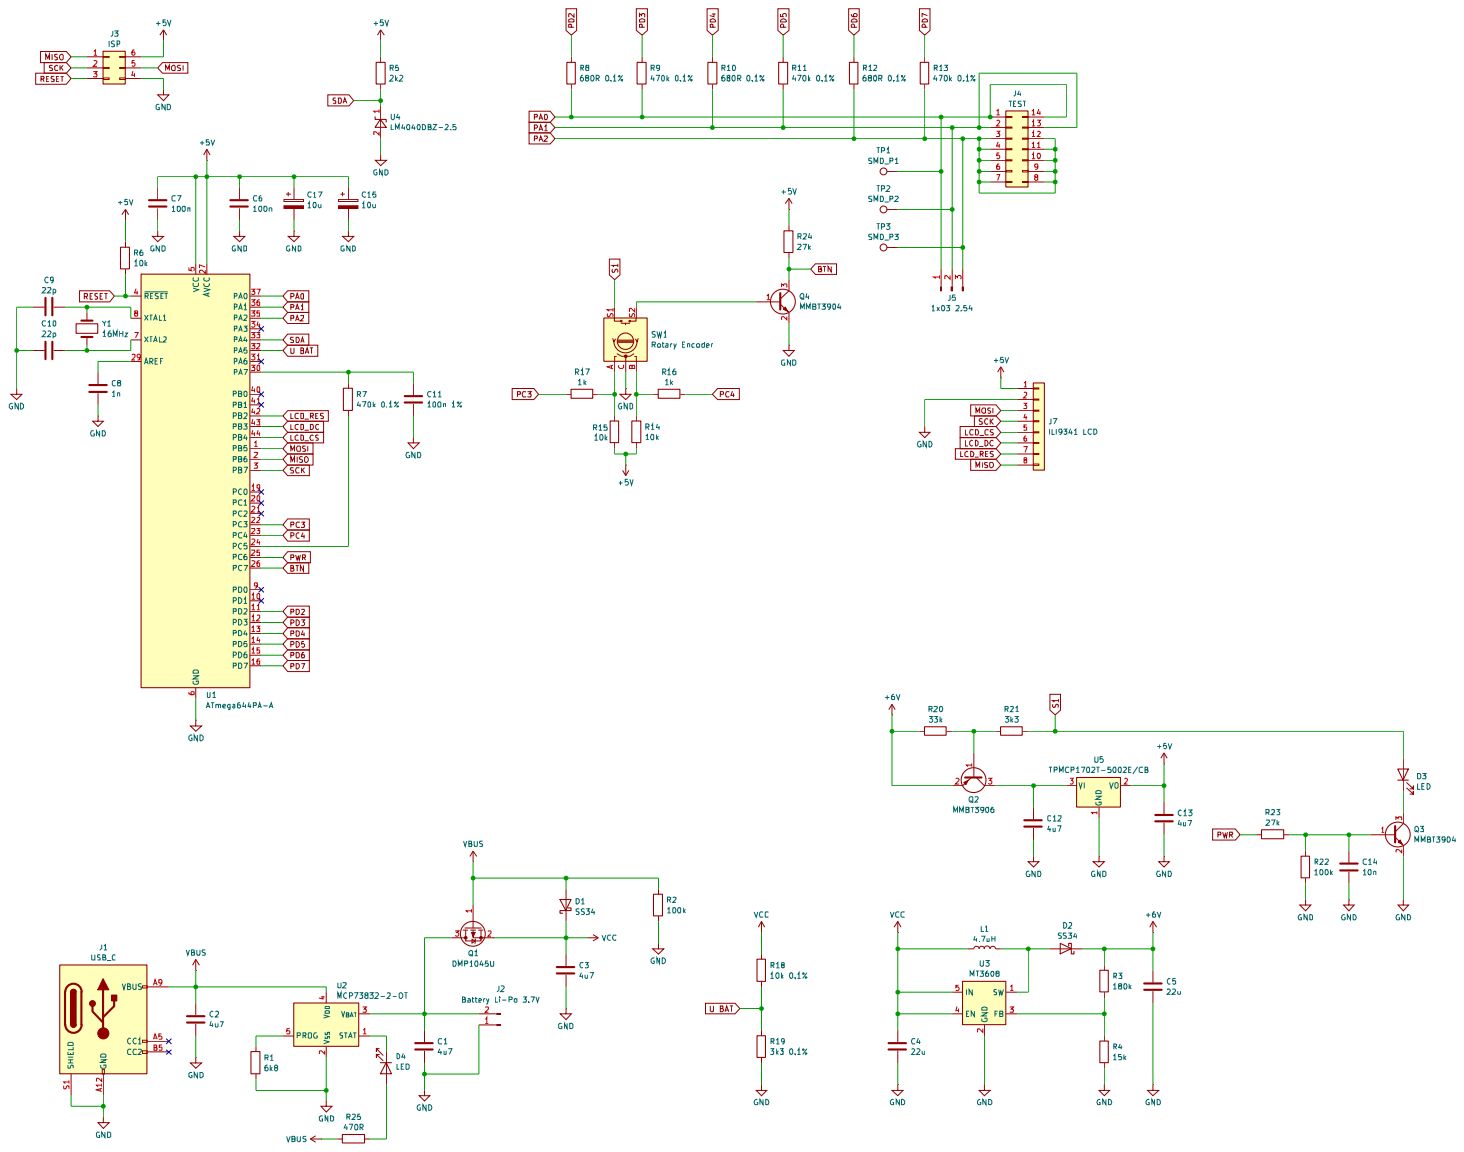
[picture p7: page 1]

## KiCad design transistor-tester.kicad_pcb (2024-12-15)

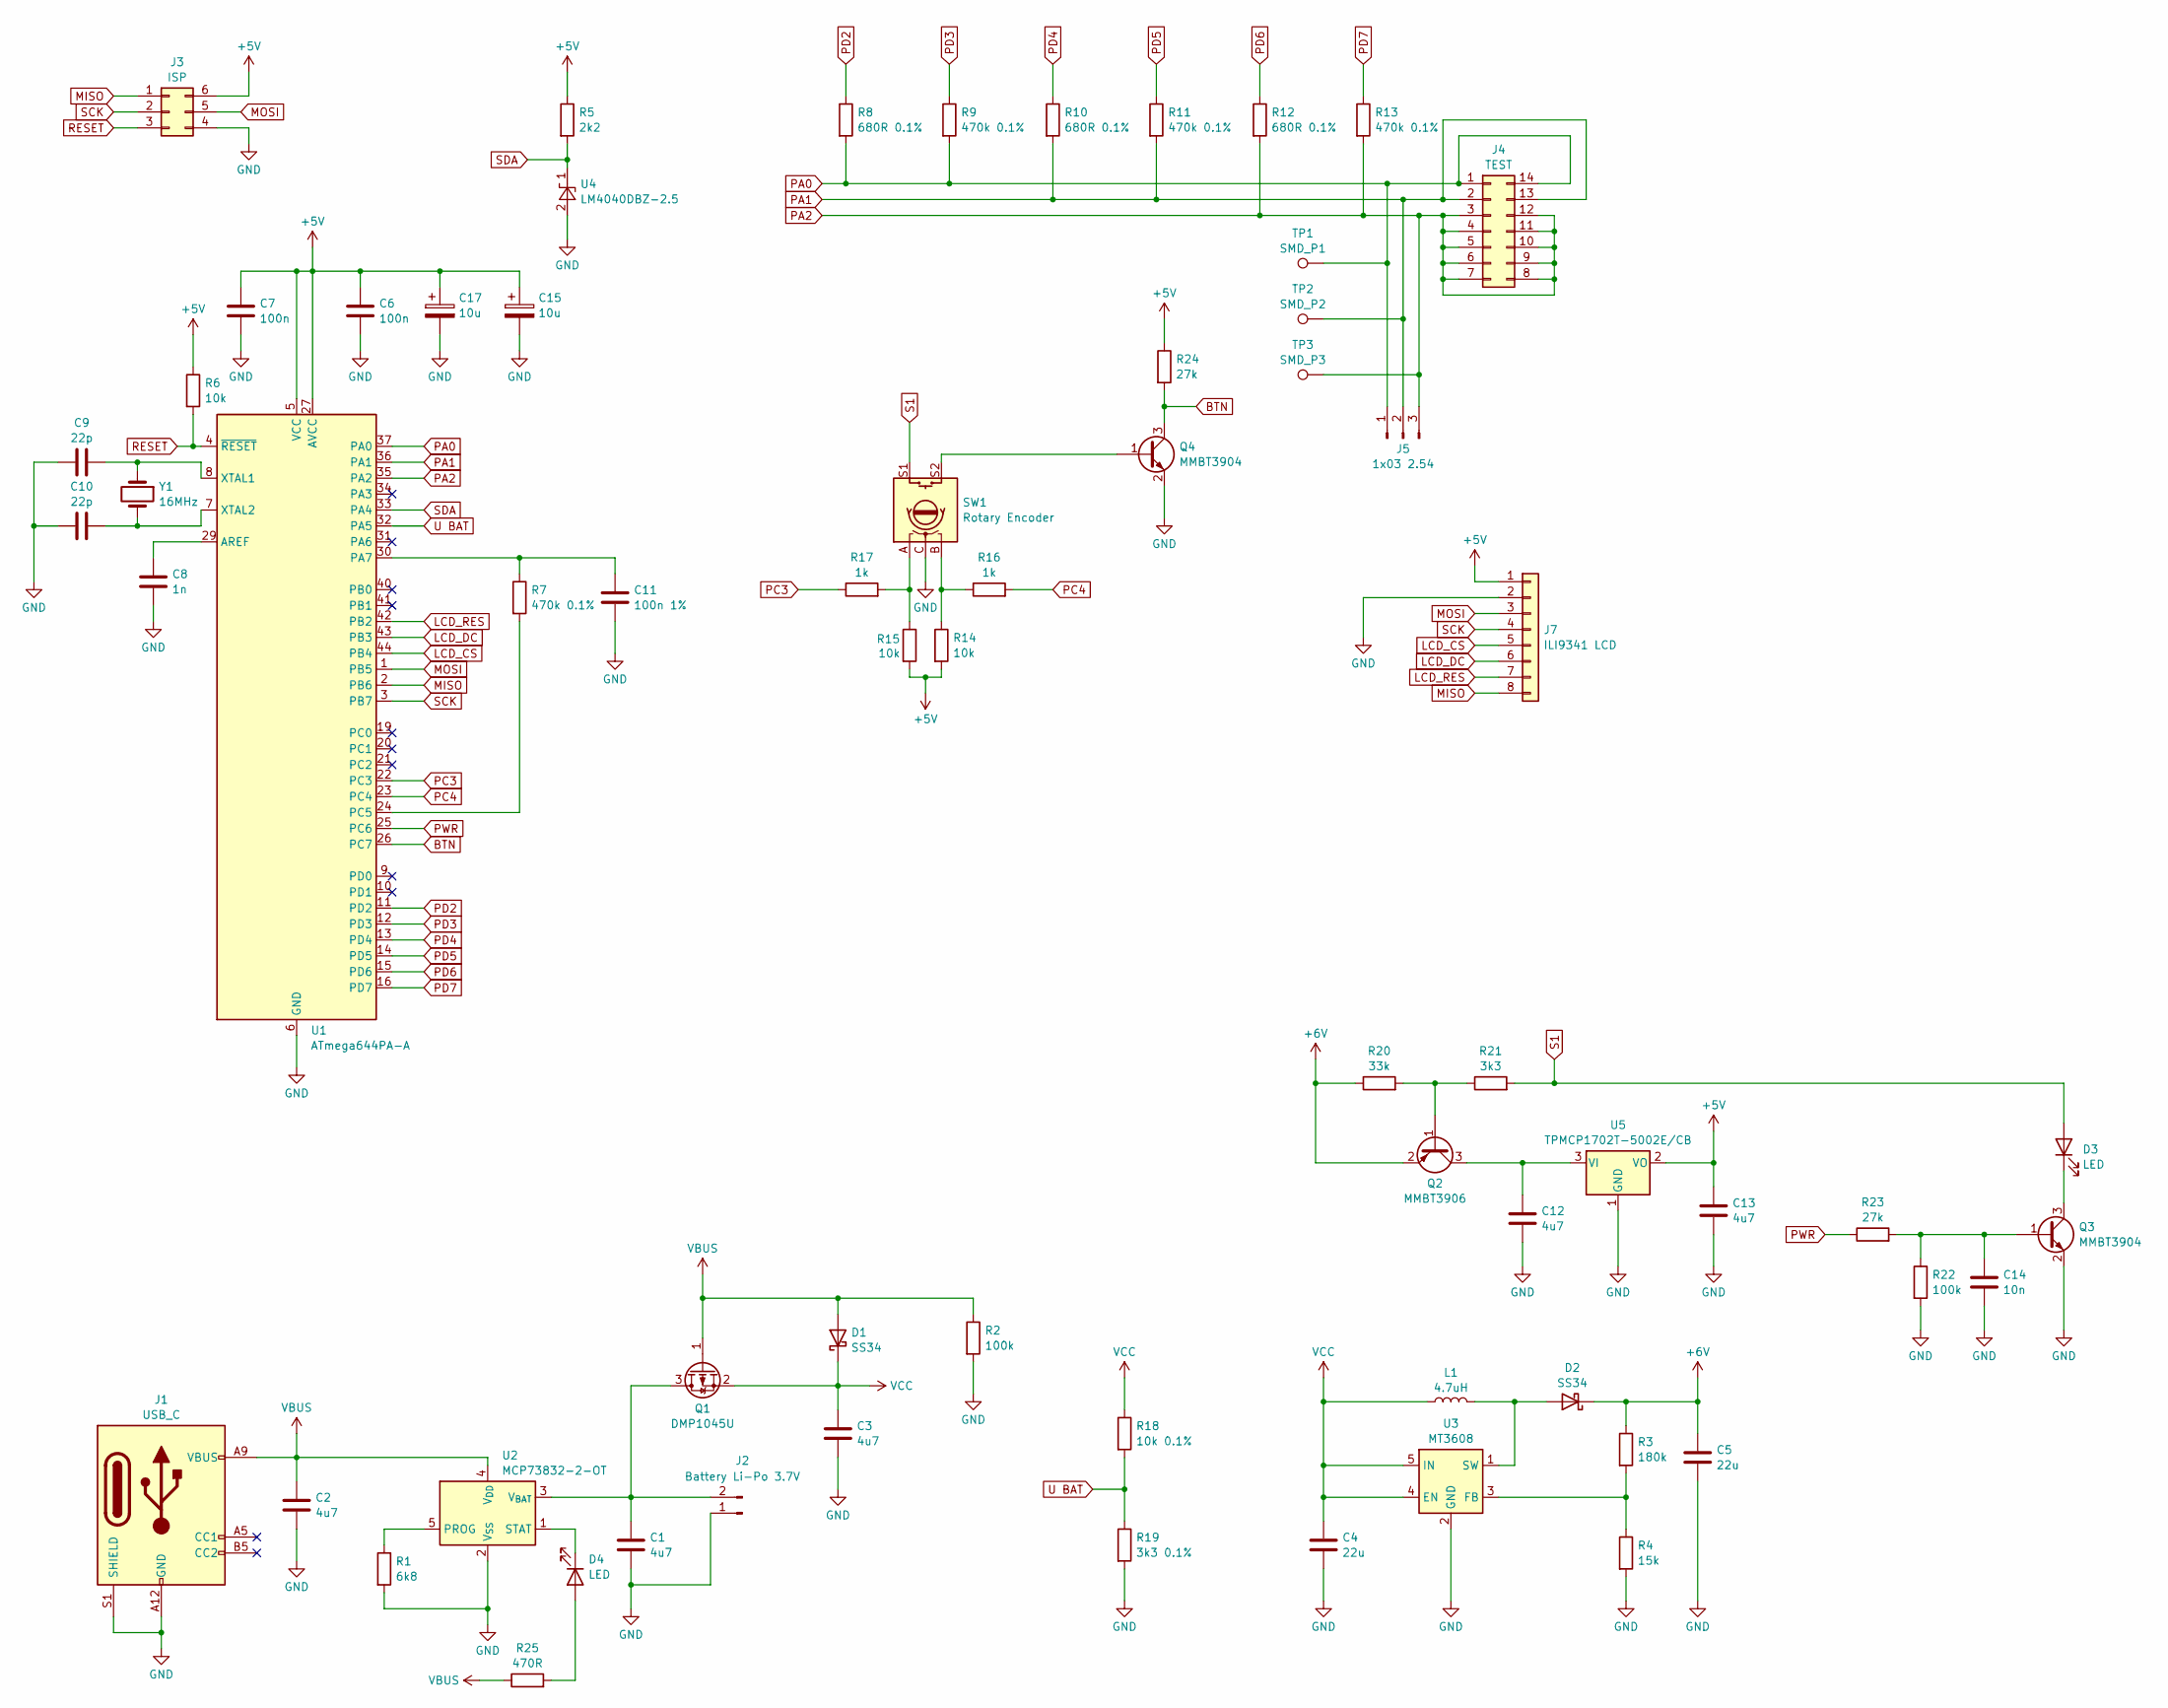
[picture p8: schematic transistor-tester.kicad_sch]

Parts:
C1, C2, C3, C12, C13: 4u7; C_1206_3216Metric; JLCPCB Part # C29823
C4, C5: 22u; C_0805_2012Metric; JLCPCB Part # C45783
C6, C7: 100n; C_0805_2012Metric
C8: 1n; C_0805_2012Metric
C9, C10: 22p; C_0805_2012Metric; JLCPCB Part # C1804
C11: 100n 1%; C_0805_2012Metric; JLCPCB Part # C2981728
C14: 10n; C_0805_2012Metric; JLCPCB Part # C1710
C15, C17: 10u; CP_EIA-3216-18_Kemet-A; JLCPCB Part # C7171
D1, D2: SS34; D_SMA; JLCPCB Part # C8678
D3, D4: LED; LED_0805_2012Metric; JLCPCB Part # C84256
J1: USB_C; USB_C_Receptacle_GCT_USB4125-xx-x-0190_6P_TopMnt_Horizontal; JLCPCB Part # C283540
J2: Battery Li-Po 3.7V; PinHeader_1x02_P2.54mm_Vertical
J3: ISP; PinHeader_2x03_P2.54mm_Vertical
J4: TEST; DIP_Socket-14_W4.3_W5.08_W7.62_W10.16_W10.9_3M_214-3339-00-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
J5: 1x03 2.54; TO-92L_Inline_Wide
J7: ILI9341 LCD; Waveshare_2.4_ILI9341_18366
L1: 4.7uH; L_1206_3216Metric; JLCPCB Part # C2941590
Q1: DMP1045U; SOT-23; JLCPCB Part # C177033
Q2: MMBT3906; SOT-23
Q3, Q4: MMBT3904; SOT-23
R1: 6k8; R_0805_2012Metric
R2, R22: 100k; R_0805_2012Metric
R3: 180k; R_0805_2012Metric
R4: 15k; R_0805_2012Metric
R5: 2k2; R_0805_2012Metric
R6, R14, R15: 10k; R_0805_2012Metric
R7, R9, R11, R13: 470k 0.1%; R_0805_2012Metric
R8, R10, R12: 680R 0.1%; R_0805_2012Metric
R16, R17: 1k; R_0805_2012Metric
R18: 10k 0.1%; R_0805_2012Metric
R19: 3k3 0.1%; R_0805_2012Metric
R20: 33k; R_0805_2012Metric
R21: 3k3; R_0805_2012Metric
R23, R24: 27k; R_0805_2012Metric
R25: 470R; R_0805_2012Metric
SW1: Rotary Encoder; RotaryEncoder_Alps_EC12E-Switch_Vertical_H20mm
TP1: SMD_P1; TestPoint_Pad_1.5x1.5mm
TP2: SMD_P2; TestPoint_Pad_1.5x1.5mm
TP3: SMD_P3; TestPoint_Pad_3.0x3.0mm
U1: ATmega644PA-A; TQFP-44_10x10mm_P0.8mm; JLCPCB Part # C38349
U2: MCP73832-2-OT; SOT-23-5; JLCPCB Part # C38066
U3: MT3608; SOT-23-6; JLCPCB Part # C2932326
U4: LM4040DBZ-2.5; SOT-23; JLCPCB Part # C9421
U5: TPMCP1702T-5002E/CB; SOT-23; JLCPCB Part # C3040636
Y1: 16MHz; Crystal_SMD_HC49-SD; JLCPCB Part # C12676

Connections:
+5V: C6.1, C7.1, C13.1, C15.1, C17.1, J3.6, J7.1, R5.1, R6.1, R14.2, R15.2, R24.1, U1.5 (VCC), U1.17 (VCC), U1.27 (AVCC), U1.38 (VCC), U5.2 (VO)
+6V: C5.1, D2.1 (K), Q2.2 (E), R3.1, R20.1
BTN: Q4.3 (C), R24.2, U1.26 (PC7)
GND: C1.2, C2.2, C3.2, C4.2, C5.2, C6.2, C7.2, C8.2, C9.2, C10.2, C11.2, C12.2, C13.2, C14.2, C15.2, C17.2, J1.A12 (GND), J1.B12 (GND), J1.S1 (SHIELD), J2.1, J3.4, J7.2, Q3.2 (E), Q4.2 (E), R1.2, R2.2, R4.2, R19.2, R22.2, SW1.C, U1.6 (GND), U1.18 (GND), U1.28 (GND), U1.39 (GND), U2.2 (V_{SS}), U3.2 (GND), U4.2 (A), U5.1 (GND)
LCD_CS: J7.5, U1.44 (PB4)
LCD_DC: J7.6, U1.43 (PB3)
LCD_RES: J7.7, U1.42 (PB2)
MISO: J3.1, J7.8, U1.2 (PB6)
MOSI: J3.5, J7.3, U1.1 (PB5)
unnamed: D2.2 (A), L1.2, U3.1 (SW)
unnamed: D3.1 (K), Q3.3 (C)
unnamed: D4.2 (A), R25.2
unnamed: D4.1 (K), U2.1 (STAT)
unnamed: C1.1, J2.2, Q1.3 (D), U2.3 (V_{BAT})
unnamed: Q2.1 (B), R20.2, R21.1
unnamed: C12.1, Q2.3 (C), U5.3 (VI)
unnamed: C14.1, Q3.1 (B), R22.1, R23.2
unnamed: Q4.1 (B), SW1.S2
unnamed: R14.1, R16.1, SW1.B
unnamed: R15.1, R17.2, SW1.A
unnamed: C8.1, U1.29 (AREF)
unnamed: C11.1, R7.1, U1.30 (PA7)
unnamed: R7.2, U1.24 (PC5)
unnamed: C9.1, U1.8 (XTAL1), Y1.1
unnamed: C10.1, U1.7 (XTAL2), Y1.2
unnamed: R1.1, U2.5 (PROG)
unnamed: R3.2, R4.1, U3.3 (FB)
PA0: J4.1, J4.14, J5.1, R8.2, R9.2, TP1.1, U1.37 (PA0)
PA1: J4.2, J4.13, J5.2, R10.2, R11.2, TP2.1, U1.36 (PA1)
PA2: J4.3, J4.4, J4.5, J4.6, J4.7, J4.8, J4.9, J4.10, J4.11, J4.12, J5.3, R12.2, R13.2, TP3.1, U1.35 (PA2)
PC3: R17.1, U1.22 (PC3)
PC4: R16.2, U1.23 (PC4)
PD2: R8.1, U1.11 (PD2)
PD3: R9.1, U1.12 (PD3)
PD4: R10.1, U1.13 (PD4)
PD5: R11.1, U1.14 (PD5)
PD6: R12.1, U1.15 (PD6)
PD7: R13.1, U1.16 (PD7)
PWR: R23.1, U1.25 (PC6)
RESET: J3.3, R6.2, U1.4 (~RESET)
S1: D3.2 (A), R21.2, SW1.S1
SCK: J3.2, J7.4, U1.3 (PB7)
SDA: R5.2, U1.33 (PA4), U4.1 (K)
U BAT: R18.2, R19.1, U1.32 (PA5)
VBUS: C2.1, D1.2 (A), J1.A9 (VBUS), J1.B9 (VBUS), Q1.1 (G), R2.1, R25.1, U2.4 (V_{DD})
VCC: C3.1, C4.1, D1.1 (K), L1.1, Q1.2 (S), R18.1, U3.4 (EN), U3.5 (IN)

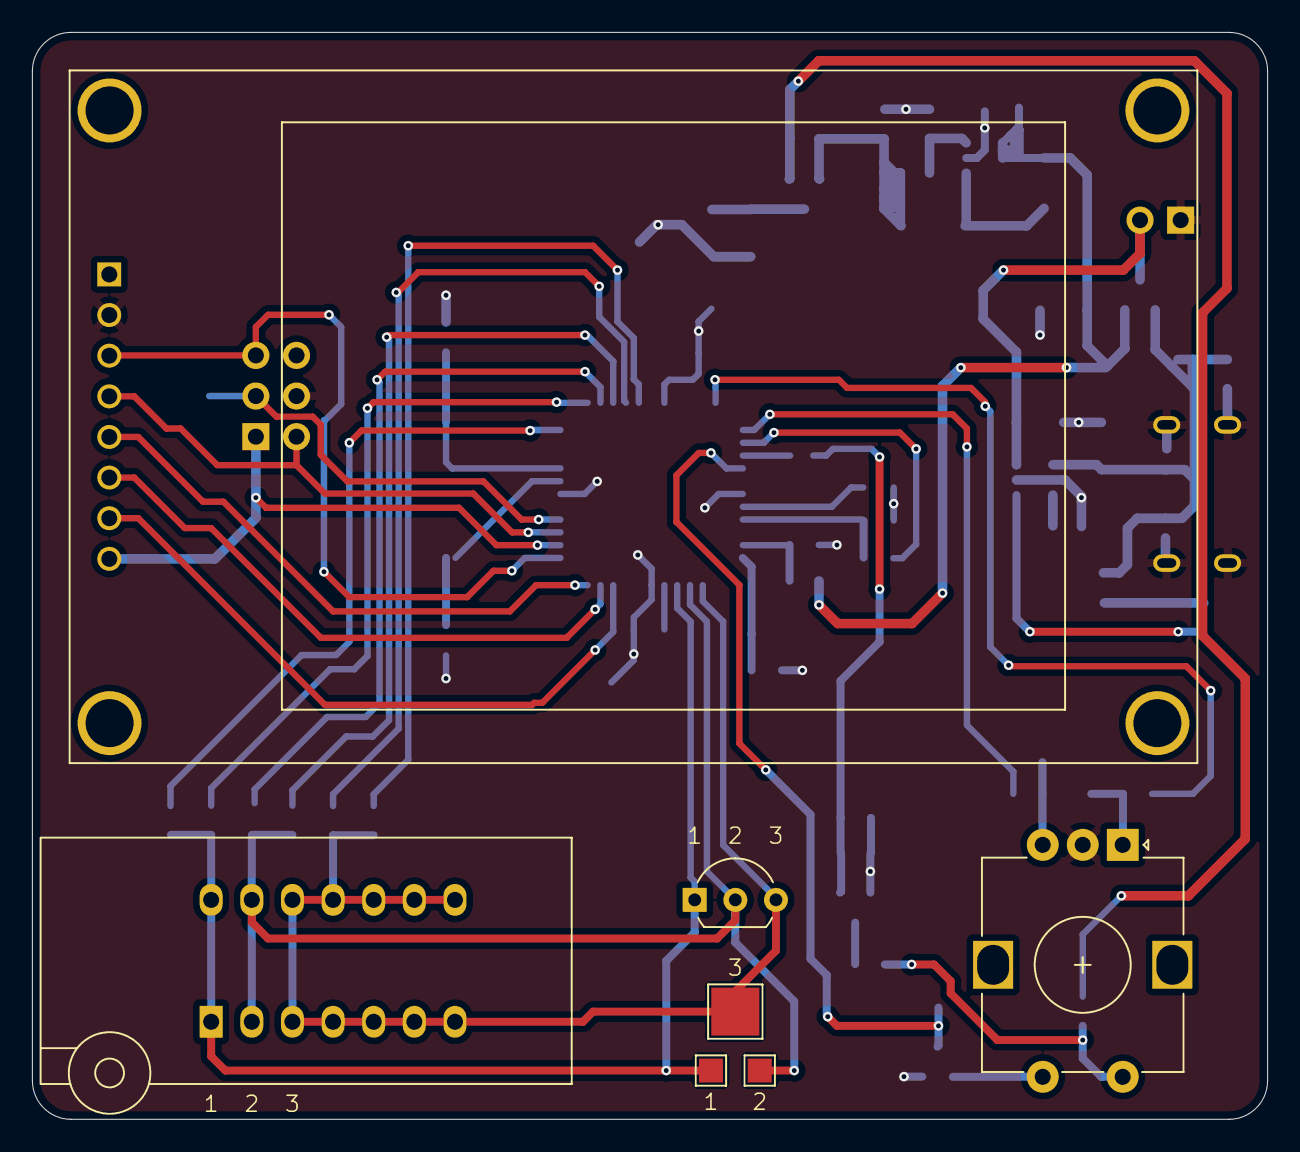
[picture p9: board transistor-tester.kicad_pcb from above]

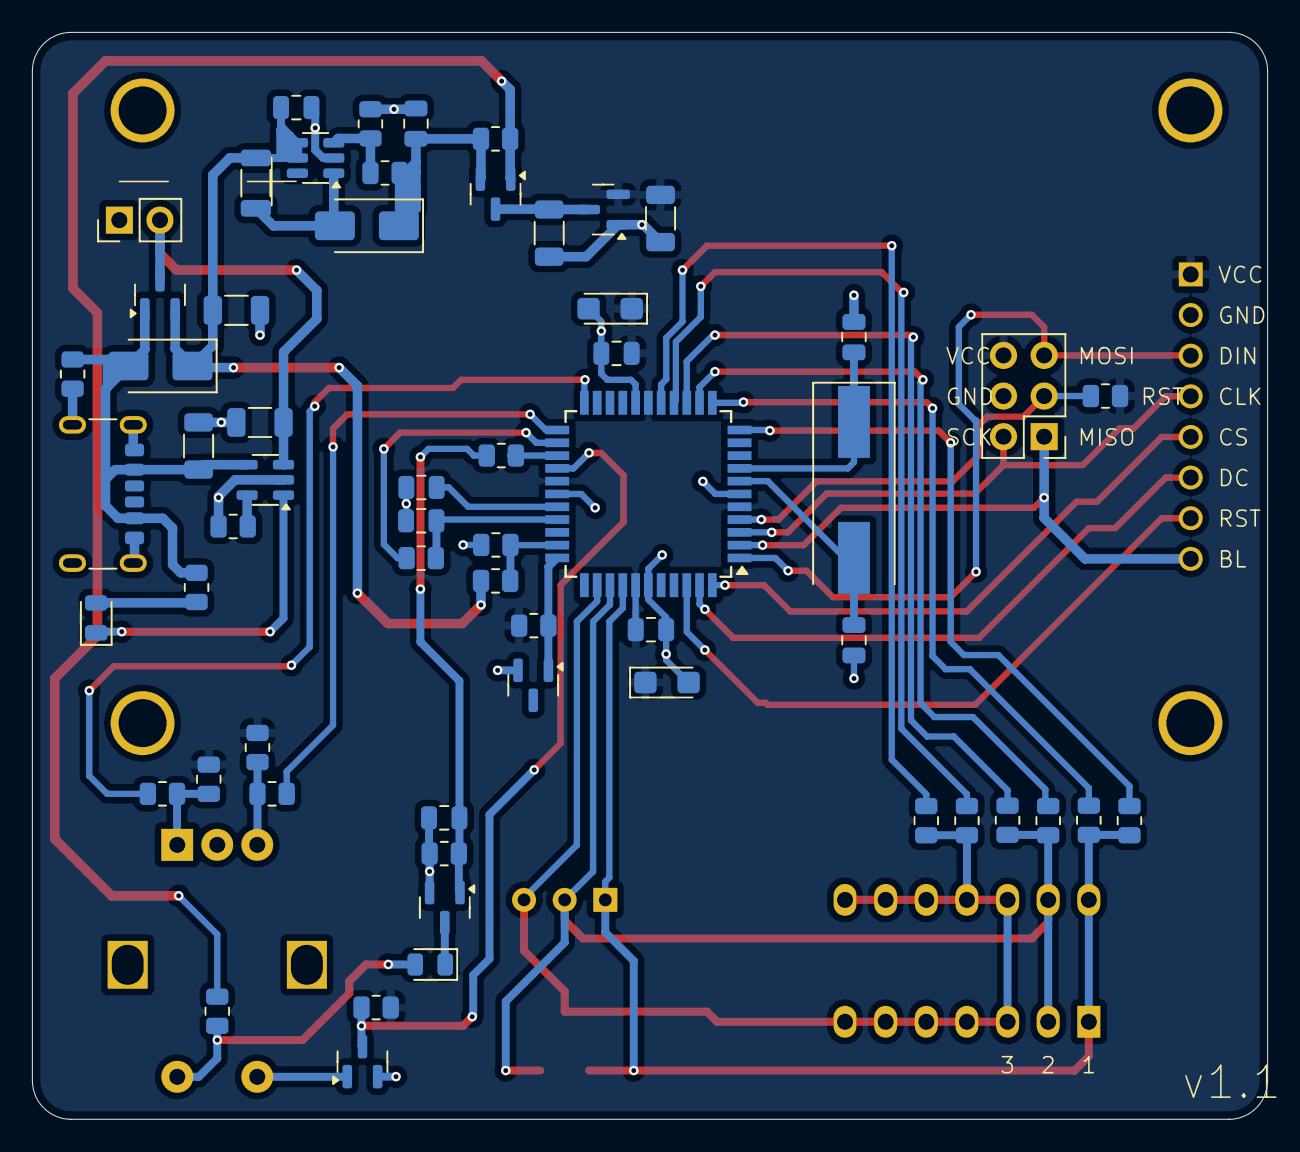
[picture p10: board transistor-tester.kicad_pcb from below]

Board: 2 copper layers, 77.2 x 67.9 mm, 66 parts (59 on the bottom side), 46 nets.

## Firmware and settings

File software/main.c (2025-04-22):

/* ************************************************************************
 *
 *   main part
 *
 *   (c) 2012-2025 by Markus Reschke
 *   based on code from Markus Frejek and Karl-Heinz Kübbeler
 *
 * ************************************************************************ */


/*
 *  local constants
 */

/* source management */
#define MAIN_C


/*
 *  include header files
 */

/* local includes */
#include "config.h"           /* global configuration */
#include "common.h"           /* common header file */
#include "variables.h"        /* global variables */
#include "functions.h"        /* external functions */
#include "colors.h"           /* color definitions */


/*
 *  local variables
 */

/* program control */
#if CYCLE_MAX < 255
uint8_t        MissedParts;          /* counter for failed/missed components */
#endif


/* ************************************************************************
 *   output components and errors
 * ************************************************************************ */


/*
 *  get pin designator for specific probe ID
 *
 *  requires:
 *  - probe ID [0-2]
 *
 *  returns:
 *  - pin designator
 */

uint8_t Get_SemiPinDesignator(uint8_t Probe)
{
  uint8_t           Char;          /* designator / return value */

  /* looking for matching probe ID */
  if (Probe == Semi.A)             /* matches pin A */
  {
    Char = Semi.DesA;              /* designator for pin A */
  }
  else if (Probe == Semi.B)        /* matches pin B */
  {
    Char = Semi.DesB;              /* designator for pin B */
  }
  else                             /* matches pin C */
  {
    Char = Semi.DesC;              /* designator for pin C */
  }

  return Char;
}



#if ! defined (UI_NO_TEXTPINOUT) || defined (SW_ENCODER)

/*
 *  show pinout for semiconductors
 *  - displays: 123=abc
 */

void Show_SemiPinout(void)
{
  uint8_t           n;             /* counter */

  /* display: 123 */
  for (n = 0; n <= 2; n++)         /* loop through probe pins */
  {
    Display_ProbeNumber(n);        /* display probe ID */
  }

  /* display: = */
  Display_Char('=');

  /* display pin designators */
  for (n = 0; n <= 2; n++)         /* loop through probe pins */
  {
    Display_SemiPinDesignator(n);  /* display pin designator */
  }
}

#endif



/*
 *  show simple pinout
 *  - displays: 1:a 2:b 3:c 
 *
 *  required:
 *  - DesX: designators for probes #1, #2 and #3
 *    0 -> not displayed
 */

void Show_SimplePinout(uint8_t Des1, uint8_t Des2, uint8_t Des3)
{
  uint8_t           n;        /* counter */
  unsigned char     Des[3];   /* component pin designators */
  #ifdef UI_PROBE_COLORS
  uint16_t          Color;    /* color value */

  Color = UI.PenColor;             /* save current color */
  #endif

  /* copy probe pin designators */
  Des[0] = Des1;
  Des[1] = Des2;
  Des[2] = Des3;

  for (n = 0; n <= 2; n++)         /* loop through probe pins */
  {
    if (Des[n] != 0)               /* display this one */
    {
      Display_ProbeNumber(n);
      Display_Colon();

      #ifdef UI_PROBE_COLORS
      UI.PenColor = ProbeColors[n];     /* set probe color */
      #endif

      Display_Char(Des[n]);

      #ifdef UI_PROBE_COLORS
      UI.PenColor = Color;              /* restore old color */
      #endif

      Display_Space();
    }
  }
}



#ifdef FUNC_EVALUE

/*
 *  show E series norm values
 *
 *  requires:
 *  - Value: unsigned value
 *  - Scale: exponent/multiplier (* 10^n)
 *  - ESeries: E6-192
 *  - Tolerance: in 0.1%
 *  - Unit: unit character
 */

void Show_ENormValues(uint32_t Value, int8_t Scale, uint8_t ESeries, uint8_t Tolerance, unsigned char Unit)
{
  uint8_t           n;             /* number of norm values (1 or 2) */
  uint8_t           Pos;           /* char x position */
  uint8_t           Temp;          /* temporary value */


  /*
   *  get E series norm values
   *  - 1st: Semi.I_value, Semi.I_scale
   *  - 2nd: Semi.C_value, Semi.C_scale
   */

  n = GetENormValue(Value, Scale, ESeries, Tolerance);


  /*
   *  show E series and tolerance
   */

  Display_NextLine();                   /* move to next line */

  /* display E series */
  Display_Char('E');                    /* display: E */
  Display_FullValue(ESeries, 0 , 0);    /* display E series */

  Display_Space();                      /* display: " " */

  /* display tolerance */
  Temp = Tolerance;                     /* copy tolerance */
  Pos = 0;                              /* reset decimal places */

  if (Temp < 10)                        /* < 1% */
  {
    Pos = 1;                            /* one decimal place */
  }
  Temp /= 10;                           /* scale to 1 */

  Display_FullValue(Temp, Pos, '%');    /* display tolerance */

  Display_Space();                      /* display: " " */


  /*
   *  show norm values
   */

  if (n)                      /* got norm value(s) */
  {
    Pos = UI.CharPos_X;       /* get current char position */

    /* display first norm value */
    Display_EValue(Semi.I_value, Semi.I_scale, Unit);

    if (n == 2)               /* got two norm values */
    {
      /* move to next line at same position (after E series) */
      Display_NextLine();
      LCD_CharPos(Pos, UI.CharPos_Y);

      /* display second norm value */
      Display_EValue(Semi.C_value, Semi.C_scale, Unit);
    }
  }
  else                        /* no norm value */
  {
    Display_Minus();          /* display: - */
  }
}

#endif



#ifdef FUNC_COLORCODE

/*
 *  show E series norm values as color-code
 *
 *  requires:
 *  - Value: unsigned value
 *  - Scale: exponent/multiplier (* 10^n)
 *  - ESeries: E6-192
 *  - Tolerance: in 0.1%
 *  - TolBand: color of tolerance band
 */

void Show_ENormCodes(uint32_t Value, int8_t Scale, uint8_t ESeries, uint8_t Tolerance, uint16_t TolBand)
{
  uint8_t           n;             /* number of norm values (1 or 2) */
  uint8_t           Pos;           /* char x position */

  /*
   *  tolerance band
   *  - resistor
   *    20%  10%    5%   2%  1%    0.5%  0.25% 0.1%   0.05%
   *    none silver gold red brown green blue  violet grey
   *  - inductor
   *    20%   10%    5%   4%     3%     2%  1%    0.5%  0.25% 0.1%   0.05%
   *    black silver gold yellow orange red brown green blue  violet grey
   *  - caps: many different schemas
   *
   *  multiplier reference
   *  - R:   0 (10^0)   -> 1 Ohms
   *    C: -12 (10^-12) -> 1 pF
   *    L:  -6 (10^-6)  -> 1 µH
   *  - ref_scale as function argument?
   *    scale = scale - ref_scale
   */

  /*
   *  get E series norm values
   *  - 1st: Semi.I_value, Semi.I_scale
   *  - 2nd: Semi.C_value, Semi.C_scale
   */

  n = GetENormValue(Value, Scale, ESeries, Tolerance);


  /*
   *  show E series
   */

  Display_NextLine();                   /* move to next line */

  /* display E series */
  Display_Char('E');                    /* display: E */
  Display_FullValue(ESeries, 0 , 0);    /* display E series */

  Display_Space();                      /* display: " " */


  /*
   *  show color-codes of norm values
   */

  if (n)                      /* got norm value(s) */
  {
    Pos = UI.CharPos_X;       /* get current char position */

    /* display color-code of first norm value */
    Display_ColorCode(Semi.I_value, Semi.I_scale, TolBand);

    if (n == 2)               /* got two norm values */
    {
      /* move to next line at same position (after E series) */
      Display_NextLine();
      LCD_CharPos(Pos, UI.CharPos_Y);

      /* display color-code of second norm value */
      Display_ColorCode(Semi.C_value, Semi.C_scale, TolBand);
    }
  }
  else                        /* no norm value */
  {
    Display_Minus();          /* display: - */
  }

  #if 0
  /*
   *  color testing
   */

  uint16_t Color;

  Display_NextLine();

  /* first 5 colors plus gold */
  n = 0;
  while (n < 5)
  {
    Color = DATA_read_word((uint16_t *)&ColorCode_table[n]);
    LCD_Band(Color, ALIGN_LEFT);
    n++;
  }
  LCD_Band(COLOR_CODE_GOLD, ALIGN_RIGHT);

  Display_NextLine();

  /* last 5 colors plus silver */
  while (n < 10)
  {
    Color = DATA_read_word((uint16_t *)&ColorCode_table[n]);
    LCD_Band(Color, ALIGN_LEFT);
    n++;
  }
  LCD_Band(COLOR_CODE_SILVER, ALIGN_RIGHT);

  TestKey(0, CURSOR_BLINK);
  #endif
}

#endif



#ifdef FUNC_EIA96

/*
 *  show E series norm values as EIA-96 code
 *  - implies E96 1%
 *
 *  requires:
 *  - Value: unsigned value
 *  - Scale: exponent/multiplier (* 10^n)
 */

void Show_ENormEIA96(uint32_t Value, int8_t Scale)
{
  uint8_t           n;             /* number of norm values (1 or 2) */

  /*
   *  get E series norm values
   *  - 1st: Semi.I_value, Semi.I_scale, Semi.A (index number)
   *  - 2nd: Semi.C_value, Semi.C_scale, Semi.B (index number)
   */

  n = GetENormValue(Value, Scale, E96, 10);

  /*
   *  show E series and tolerance
   */

  Display_NextLine();                   /* move to next line */

  /* display E series (E96) */
  Display_Char('E');                    /* display: E */
  Display_FullValue(96, 0, 0);          /* display E series */

  Display_Space();                      /* display: " " */

  /* display tolerance (1%) */
  Display_FullValue(1, 0, '%');         /* display tolerance */

  Display_Space();                      /* display: " " */


  /*
   *  show EIA-96 codes of norm values
   */

  if (n)                      /* got norm value(s) */
  {
    /* display EIA-96 code of first norm value */
    Display_EIA96(Semi.A, Semi.I_scale);

    if (n == 2)               /* got two norm values */
    {
      Display_Space();                  /* display: " " */

      /* display EIA-96 code of second norm value */
      Display_EIA96(Semi.B, Semi.C_scale);
    }
  }
  else                        /* no norm value */
  {
    Display_Minus();          /* display: - */
  }
}

#endif



/*
 *  show failed test
 *  - no component found
 */

void Show_Fail(void)
{
  /* display info */
  #ifdef UI_CENTER_ALIGN
    Display_CenterLine(2);                        /* center block: 2 lines */
    Display_EEString_Center(Failed1_str);         /* display: No component */
    Display_NL_EEString_Center(Failed2_str);      /* display: found! */
  #else
    Display_EEString(Failed1_str);      /* display: No component */
    Display_NL_EEString(Failed2_str);   /* display: found! */
  #endif

  #ifdef UI_QUESTION_MARK
  /* display question mark symbol */
  Check.Symbol = SYMBOL_QUESTIONMARK;   /* set symbol ID */
    #ifdef UI_CENTER_ALIGN
      Display_FancySemiPinout(1);       /* show symbol starting in line #1 */
    #else
      Display_FancySemiPinout(3);       /* show symbol starting in line #3 */
    #endif
  #endif

  #if CYCLE_MAX < 255
  MissedParts++;              /* increase counter */
  #endif
}



/*
 *  show error
 */

void Show_Error()
{
  if (Check.Type == TYPE_DISCHARGE)          /* discharge failed */
  {
    /* possibly a voltage source */
    Display_EEString(DischargeFailed_str);   /* display: Battery? */

    /* display probe number and remaining voltage */
    Display_NextLine();
    Display_ProbeNumber(Check.Probe);
    Display_Colon();
    Display_Space();
    Display_Value(Check.U, -3, 'V');
  }
  else if (Check.Type == TYPE_DETECTION)     /* detection error */
  {
    /* simply display: No component found! */
    Show_Fail();
  }
}



#ifdef UI_PROBE_COLORS

/*
 *  show single (first) resistor
 *
 *  requires:
 *  - Probe1: probe ID #1 [0-2]
 *  - Probe2: probe ID #2 [0-2]
 *  - Mode: 0 for probe ID
 *          >0 for pin designator
 */

void Show_SingleResistor(uint8_t Probe1, uint8_t Probe2, int8_t Mode)
{
  Resistor_Type     *Resistor;     /* pointer to resistor */

  Resistor = &Resistors[0];        /* pointer to first resistor */

  /*
   *  show pinout
   */

  if (Mode)
  {
    Display_SemiPinDesignator(Probe1);
  }
  else
  {
    Display_ProbeNumber(Probe1);
  }

  Display_EEString(Resistor_str);

  if (Mode)
  {
    Display_SemiPinDesignator(Probe2); 
  }
  else
  {
    Display_ProbeNumber(Probe2);
  }

  /* show resistance value */
  Display_Space();
  Display_Value(Resistor->Value, Resistor->Scale, LCD_CHAR_OMEGA);
}

#else

/*
 *  show single (first) resistor
 *
 *  requires:
 *  - ID1: pin ID #1 character
 *  - ID2: pin ID #2 character
 */

void Show_SingleResistor(uint8_t ID1, uint8_t ID2)
{
  Resistor_Type     *Resistor;     /* pointer to resistor */

  Resistor = &Resistors[0];        /* pointer to first resistor */

  /* show pinout */
  Display_Char(ID1);
  Display_EEString(Resistor_str);
  Display_Char(ID2); 

  /* show resistance value */
  Display_Space();
  Display_Value(Resistor->Value, Resistor->Scale, LCD_CHAR_OMEGA);
}

#endif



/*
 *  show resistor(s)
 */
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
int main(void)
{
  uint8_t           Test;          /* test value */
  uint8_t           Key;           /* user feedback */
  #ifdef UI_MAINMENU_POWERON_BUTTON
  uint8_t           Key2 = 0;      /* user feedback #2 */
  #endif


  /*
   *  init hardware
   */

  #ifdef POWER_SWITCH_SOFT
    #ifdef PASSIVE_POWER_CTRL
      /* switch on power to keep me alive (passive way) */
      /* pin in input mode and low by default */
    #else
      /* switch on power to keep me alive (standard way) */
      POWER_DDR = (1 << POWER_CTRL);        /* set pin as output */
      POWER_PORT = (1 << POWER_CTRL);       /* set pin high to drive power management transistor */
    #endif
  #endif

  /* set up MCU */
  MCUCR = (1 << PUD);                   /* disable pull-up resistors globally */
  ADCSRA = (1 << ADEN) | ADC_CLOCK_DIV; /* enable ADC and set clock divider */

  #ifdef HW_DISCHARGE_RELAY
  /* init discharge relay (safe mode): short circuit probes */
                                        /* ADC_PORT should be 0 */
  ADC_DDR = (1 << TP_REF);              /* disable relay */
  #endif

  /* catch watchdog */  
  Test = (MCUSR & (1 << WDRF));         /* save watchdog flag */
  MCUSR &= ~(1 << WDRF);                /* reset watchdog flag */
  wdt_disable();                        /* disable watchdog */


  /*
   *  set important default values
   */

  #if defined (UI_AUTOHOLD) || defined (UI_SERIAL_COMMANDS)
    /* reset mode/state flags and set auto-hold mode */
    Cfg.OP_Mode = OP_AUTOHOLD;          /* set auto-hold */
  #else
    /* reset mode/state flags and set continuous mode */
    Cfg.OP_Mode = OP_NONE;              /* none = continuous */
  #endif
  Cfg.OP_Control = OP_OUT_LCD;          /* reset control/signal flags */
                                        /* enable output to display */
  #ifdef SAVE_POWER
  Cfg.SleepMode = SLEEP_MODE_PWR_SAVE;  /* sleep mode: power save */
  #endif                                /* we have to keep Timer2 running */


  /*
   *  set up busses and interfaces
   */

  /* test push button */
  /* set to input by default */

  #ifdef HW_SERIAL
  /* hardware or bitbang USART */
  Serial_Setup();                       /* set up TTL serial interface */
  #endif

  #ifdef HW_I2C
  /* hardware or bitbang I2C */
  I2C_Setup();                          /* set up I2C bus */
  #endif

  #ifdef HW_SPI
  /* hardware or bitbang SPI */
  SPI_Setup();                          /* set up SPI bus */
  #endif

  /* display module */
  LCD_BusSetup();                       /* set up display bus */

  #ifdef HW_TOUCH
  /* touch screen */
  Touch_BusSetup();                     /* set up touch screen bus */
  #endif

  #ifdef ONEWIRE_IO_PIN
  /* OneWire with dedicated IO pin */
  OneWire_Setup();                      /* set up OneWire bus */
  #endif

  #ifdef HW_MAX6675
  /* MAX6675 thermocouple converter */
  MAX6675_BusSetup();                   /* set up MAX6675's bus */
  #endif

  #ifdef HW_MAX31855
  /* MAX31855 thermocouple converter */
  MAX31855_BusSetup();                  /* set up MAX31855's bus */
  #endif


  /*
   *  watchdog was triggered (timeout 2s)
   *  - This is after the MCU has performed a reset driven by the watchdog.
   *  - Does only work if the capacitor at the base of the power management
   *    transistor is large enough to survive a MCU reset. Otherwise the
   *    tester simply loses power.
   */

  if (Test)
  {
    /*
     *  inform user
     *  - Display was initialized before but some global variables in the
     *    driver might be zeroed. Drivers with line tracking won't clear screen.
     */

    LCD_Clear();                        /* clear display */
    #ifdef LCD_COLOR
    UI.PenColor = COLOR_ERROR;          /* set pen color */
    #endif
    #ifdef UI_CENTER_ALIGN
      Display_CenterLine(2);                 /* center block: 2 lines */
      Display_EEString_Center(Timeout_str);  /* display: timeout */
      Display_NL_EEString_Center(Error_str); /* display: error */
    #else
      Display_EEString(Timeout_str);    /* display: timeout */
      Display_NL_EEString(Error_str);   /* display: error */
    #endif
    MilliSleep(2000);                   /* give user some time to read */

    /* power down */
    #ifdef POWER_SWITCH_SOFT
      POWER_PORT &= ~(1 << POWER_CTRL);      /* power off myself: set pin low */
      #ifdef PASSIVE_POWER_CTRL
      POWER_DDR |= (1 << POWER_CTRL);        /* set pin to output mode */
      #endif
    #elif defined (POWER_SWITCH_MANUAL)
      /* enter sleep mode to prevent any further action */
      /* user should power off tester */
      set_sleep_mode(SLEEP_MODE_PWR_DOWN);   /* set sleep mode to "power down" */
      sleep_mode();                          /* enter sleep mode */
    #endif

    return 0;                           /* exit program */
  }


  /*
   *  operation mode selection
   *  - short key press -> continuous mode
   *  - long key press -> auto-hold mode
   *  - very long key press -> reset to defaults (adjustments)
   */

  Key = 0;                              /* reset key press type */

  /* catch key press */
  if (!(BUTTON_PIN & (1 << TEST_BUTTON)))    /* test button pressed */
  {
    Test = 0;                      /* ticks counter */

    while (Key == 0)               /* loop until we got a type */
    {
      MilliSleep(20);                        /* wait 20ms */

      if (!(BUTTON_PIN & (1 << TEST_BUTTON)))   /* button still pressed */
      {
        Test++;                                   /* increase counter */
        if (Test > 100) Key = KEY_DEFAULTS;       /* >2000ms: set defaults */
      }
      else                                      /* button released */
      {
        Key = KEY_SHORT;                          /* <300ms: short press */
        if (Test > 15) Key = KEY_LONG;            /* >300ms: long press */

        #ifdef UI_MAINMENU_POWERON_BUTTON
        /* check for second key press */
        MilliSleep(50);                        /* delay before checking again */
        Test = 20;                             /* timeout of 200ms */

        while (Test > 0)                     /* timeout loop */
        {
          Key2 = BUTTON_PIN & (1 << TEST_BUTTON);      /* get button status */

          if (Key2 == 0)                     /* button pressed */
          {
            MilliSleep(30);                            /* time to debounce */
            Key2 = BUTTON_PIN & (1 << TEST_BUTTON);    /* get button status */

            if (Key2 == 0)                   /* button still pressed */
            {
              Test = 1;                           /* end loop */
              Key2 = KEY_MAINMENU;                /* set key: enter main menu */
            }
          }

          Test--;                            /* decrease timeout */
          MilliSleep(10);                    /* wait 10ms */
        }
        #endif
      }
    }
  }

  #ifndef UI_SERIAL_COMMANDS
  /* long key press >300ms selects alternative operation mode */
  if (Key > KEY_SHORT)
  {
    #ifdef UI_AUTOHOLD
      /* change mode to continuous */
      Cfg.OP_Mode &= ~OP_AUTOHOLD;      /* clear auto-hold */
    #else
      /* change mode to auto-hold */
      Cfg.OP_Mode |= OP_AUTOHOLD;       /* set auto-hold */
    #endif
  }
  #endif

  #ifdef POWER_OFF_TIMEOUT
  /* automatic power-off for auto-hold mode */
  if (Cfg.OP_Mode & OP_AUTOHOLD)        /* in auto-hold mode */
  {
    Cfg.OP_Control |= OP_PWR_TIMEOUT;   /* enable power-off timeout */
  }
  #endif


  /*
   *  init display module
   */

  #ifdef SW_DISPLAY_ID
  Cfg.DisplayID = 0;                    /* reset display ID */
  #endif

  LCD_Init();                           /* initialize LCD */

  UI.LineMode = LINE_STD;               /* reset next-line mode */
  #ifdef LCD_COLOR
  UI.PenColor = COLOR_INFO;             /* set pen color */
  #endif

  #ifdef HW_TOUCH
  Touch_Init();                         /* init touch screen */
  #endif


  /*
   *  init additional hardware
   */

  #ifdef HW_BUZZER
  /* set up port pin for buzzer control: off by default */
  BUZZER_PORT &= ~(1 << BUZZER_CTRL);   /* set pin low */
  BUZZER_DDR |= (1 << BUZZER_CTRL);     /* enable output */
  #endif

  #ifdef ZENER_SWITCHED
  /* set up port pin for boost converter control: off by default */
    #ifdef ZENER_BOOST_HIGH
      /* high active */
      BOOST_PORT &= ~(1 << BOOST_CTRL);    /* set pin low */
    #else
      /* low active */
      BOOST_PORT |= (1 << BOOST_CTRL);     /* set pin high */
    #endif
  BOOST_DDR |= (1 << BOOST_CTRL);          /* enable output */
  #endif
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

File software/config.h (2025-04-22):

/* ************************************************************************
 *
 *   global configuration, setup and settings
 *
 *   (c) 2012-2025 by Markus Reschke
 *   based on code from Markus Frejek and Karl-Heinz K�bbeler
 *
 * ************************************************************************ */


/* source management */
#define CONFIG_H


/*
 *  For MCU specific settings (port and pin assignments) and display
 *  settings please edit also:
 *  - ATmega328:            config_328.h
 *  - ATmega324/644/1284:   config_644.h
 *  - ATmega640/1280/2560:  config_1280.h
 */



/* ************************************************************************
 *   Hardware options
 * ************************************************************************ */


/*
 *  rotary encoder for user interface
 *  - default pins: PD2 & PD3 (ATmega 328)
 *  - could be in parallel with LCD module
 *  - see ENCODER_PORT in config-<MCU>.h for port pins
 *  - uncomment to enable and also set ENCODER_PULSES & ENCODER_STEPS below
 *    to match your rotary encoder
 */

#define HW_ENCODER


/*
 *  Number of Gray code pulses per step or detent for the rotary encoder
 *  - typical values: 2 or 4, rarely 1
 *  - a rotary encoder's pulse is the complete sequence of 4 Gray code pulses
 *  - adjust value to match your rotary encoder
 */

#define ENCODER_PULSES   4


/*
 *  Number of detents or steps
 *  - this is used by the detection of the rotary encoder's turning velocity
 *  - it doesn't have to match exactly and also allows you to finetune the
 *    the feedback (higher: slow down, lower: speed up)
 *  - typical values: 20, 24 or 30
 *  - adjust value to match your rotary encoder
 */

#define ENCODER_STEPS    24


/*
 *  increase/decrease push buttons for user interface
 *  - alternative for rotary encoder
 *  - see KEY_PORT in config-<MCU>.h for port pins
 *  - uncomment to enable
 */

//#define HW_INCDEC_KEYS


/*
 *  2.5V voltage reference for Vcc check
 *  - default pin: PC4 (ATmega 328)
 *  - should be at least 10 times more precise than the voltage regulator
 *  - see TP_REF in config-<MCU>.h for port pin
 *  - uncomment to enable and also adjust UREF_25 below for your voltage
 *    reference
 */

#define HW_REF25


/*
 *  Typical voltage of 2.5V voltage reference (in mV)
 *  - see datasheet of the voltage reference
 *  - or use >= 5.5 digit DMM to measure the voltage
 */

#define UREF_25           2495


/*
 *  Probe protection relay for discharging caps
 *  - default pin: PC4 (ATmega 328)
 *  - low signal: short circuit probe pins
 *    high signal via external reference: remove short circuit
 *  - see TP_REF in config_<MCU>.h for port pin
 *  - uncomment to enable
 */

//#define HW_DISCHARGE_RELAY


/*
 *  Zener check / voltage measurement up to 50V DC
 *  - default pin: PC3 (ATmega 328)
 *  - uses voltage divider (standard: 10:1)
 *  - DC-DC boost converter controlled by test push button
 *    (for alternative control modes see below)
 *  - see TP_ZENER in config_<MCU>.h for port pin
 *  - uncomment to enable
 */

//#define HW_ZENER


/*
 *  non-standard voltage divider for Zener check
 *  - standard voltage divider is 10:1
 *  - ZENER_R1: top resistor in Ohms
 *  - ZENER_R2: bottom resistor in Ohms
 *  - uncomment to enable and adjust resistor values
 */

//#define ZENER_DIVIDER_CUSTOM
#define ZENER_R1         180000
#define ZENER_R2         20000


/*
 *  alternative mode for Zener check: don't switch boost converter
 *  - when the DC-DC boost converter runs all the time or when just
 *    measuring an external voltage (circuit without boost converter)
 *  - uncomment to enable
 */

//#define ZENER_UNSWITCHED


/*
 *  alternative mode for Zener check: switch converter via dedicated MCU pin
 *  - boost converter is controlled by a dedicated I/O pin
 *  - see BOOST_PORT in config_<MCU>.h for port pin
 *  - two drive methods:
 *    ZENER_BOOST_HIGH   high active / enabled when high
 *    ZENER_BOOST_LOW    low active / enabled when low
 *  - uncomment to enable and choose one drive method
 */

//#define ZENER_SWITCHED
//#define ZENER_BOOST_HIGH                /* high active */
#define ZENER_BOOST_LOW                 /* low active */


/*
 *  Zener check during normal probing
 *  - requires boost converter running all the time (ZENER_UNSWITCHED)
 *  - uncomment to enable
 *  - The min/max voltages are meant for the detection of a valid Zener voltage.
 *    The min. voltage should be higher than the noise floor, while the max.
 *    voltage should be lower than the boost converter's output voltage.
 */

//#define HW_PROBE_ZENER
#define ZENER_VOLTAGE_MIN     1000      /* min. voltage in mV */
#define ZENER_VOLTAGE_MAX     30000     /* max. voltage in mV */


/*
 *  fixed signal output
 *  - in case the MCU's OC1B pin is wired as dedicated signal output
 *    instead of driving the Rl probe resistor for test pin #2
 *  - uncomment to enable
 */

//#define HW_FIXED_SIGNAL_OUTPUT
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

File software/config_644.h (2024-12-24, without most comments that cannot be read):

/* ************************************************************************
 *
 *   ATmega 324/644/1284 specific global configuration, setup and settings
 *
 *   (c) 2012-2024 by Markus Reschke
 *   based on code from Markus Frejek and Karl-Heinz K�bbeler
 *
 * ************************************************************************ */


/* source management */
#define CONFIG_644_H



/* ************************************************************************
 *   display module
 * ************************************************************************ */


/*
 *  display module / controller
 *
 *  Please uncomment the package matching your LCD/OLED module and adjust
 *  settings. And comment out the default package (ILI9342, hardware SPI)
 *  if not used.
 *
 *  To uncomment, remove the enclosing "#if 0" and "#endif" or put
 *  a "//" in front of both. To comment out, remove the "//" in front
 *  of the "#if 0" and "#endif".
 *
 *  Individual settings can be enabled by removing the leading "//", or
 *  disabled by placing a "//" in front of the setting.
 */


/*
 *  HD44780
 *  - 4 bit parallel interface
 *  - enable LCD_DB_STD when using port pins 0-3 for LCD_DB4/5/6/7
 */

#if 0
#define LCD_HD44780                     /* display controller HD44780 */
#define LCD_TEXT                        /* character display */
#define LCD_PAR_4                       /* 4 bit parallel interface */
/* control and data lines */
#define LCD_PORT         PORTB          /* port data register */
#define LCD_DDR          DDRB           /* port data direction register */
//#define LCD_DB_STD                      /* use standard pins 0-3 for DB4-7 */
#define LCD_DB4          PB4            /* port pin used for DB4 */
#define LCD_DB5          PB5            /* port pin used for DB5 */
#define LCD_DB6          PB6            /* port pin used for DB6 */
#define LCD_DB7          PB7            /* port pin used for DB7 */
#define LCD_RS           PB2            /* port pin used for RS */
#define LCD_EN1          PB3            /* port pin used for E */
/* display settings */
#define LCD_CHAR_X       16             /* characters per line */
#define LCD_CHAR_Y       2              /* number of lines */
/* HD44780 has an internal 5x7 font */
#define FONT_HD44780_INT                /* International font (English) */
//#define FONT_HD44780_WIN1251            /* Cyrillic font (European) */
#endif



/*
 *  HD44780 with PCF8574 based backpack
 *  - I2C interface using hardware I2C
 *  - if you change LCD_DB4/5/6/7 comment out LCD_DB_STD!
 *  - hardware I2C automatically selects SDA and SCL pins
 *  - PCF8574T is 0x27, PCF8574AT is 0x3f
 */

#if 0
#define LCD_HD44780                     /* display controller HD44780 */
#define LCD_TEXT                        /* character display */
#define LCD_PCF8574                     /* PCF8574 backpack */
#define LCD_I2C_ADDR     0x27           /* PCF8574's I2C address */
/* control and data lines */
#define LCD_DB_STD                      /* use standard pins 4-7 for DB4-7 */
#define LCD_DB4          PCF8574_P4     /* port pin used for DB4 */
#define LCD_DB5          PCF8574_P5     /* port pin used for DB5 */
#define LCD_DB6          PCF8574_P6     /* port pin used for DB6 */
#define LCD_DB7          PCF8574_P7     /* port pin used for DB7 */
#define LCD_RS           PCF8574_P0     /* port pin used for RS */
#define LCD_RW           PCF8574_P1     /* port pin used for RW */
#define LCD_EN1          PCF8574_P2     /* port pin used for E */
#define LCD_LED          PCF8574_P3     /* port pin used for backlight */
/* display settings */
#define LCD_CHAR_X       16             /* characters per line */
#define LCD_CHAR_Y       2              /* number of lines */
//#define LCD_BACKLIGHT_LOW               /* backlight is low active */
/* HD44780 has an internal 5x7 font */
#define FONT_HD44780_INT                /* International font (English) */
//#define FONT_HD44780_WIN1251            /* Cyrillic font (European) */
/* I2C bus */
#define I2C_HARDWARE                    /* hardware I2C (MCU's TWI) */
#define I2C_STANDARD_MODE               /* 100kHz bus speed */
#endif



/*
 *  ILI9163
 *  - 4 wire SPI interface using hardware SPI
 */
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

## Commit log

2024-12-15 intial commit
    [TTester-BOM_JLCSMT.xlsx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]
2025-04-22 Update BOM
    [TTester-BOM_JLCSMT.xlsx]
2025-04-22 fix Ge BJT detection
    [semi.c]
2025-10-30 Add files via upload
    add LCSC Part #
    [TTester-BOM_JLCSMT.xlsx]
2025-10-30 add missing LCSC Part #
    [TTester-BOM_JLCSMT.xlsx]
2025-10-30 cpl Pick&Place file for JLCPCB
    pick and place file generated from gerber in kicad. partially reformatted according to JLCPCB support manual with chatGPT, tested on JLCPCB site assembly section.
    [transistor-tester-bottom-pos.csv]
